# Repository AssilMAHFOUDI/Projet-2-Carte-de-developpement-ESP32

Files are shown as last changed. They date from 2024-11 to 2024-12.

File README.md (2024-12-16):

Le but de cette carte électronique est de servir de plateforme polyvalente et flexible pour
différentes applications. Elle peut être alimentée de plusieurs manières, ce qui permet une
adaptabilité en fonction des sources d’énergie disponibles.
Elle est aussi dotée de capteurs pour mesurer le courant et la température, ce qui peut être
utile pour le suivi et la surveillance de performances ou pour la protection de dispositifs.
L'interface homme-machine (IHM), avec un buzzer, une LED, et une connectivité BLE, permet
une interaction facile avec l’utilisateur.
La possibilité de boot et reset matériel permet une gestion directe de la carte. Enfin, la
compatibilité avec les modules MikroBus et Grove garantit une extension facile, ajoutant des
fonctionnalités supplémentaires pour diverses applications.
###plus d'informations dans le rapport

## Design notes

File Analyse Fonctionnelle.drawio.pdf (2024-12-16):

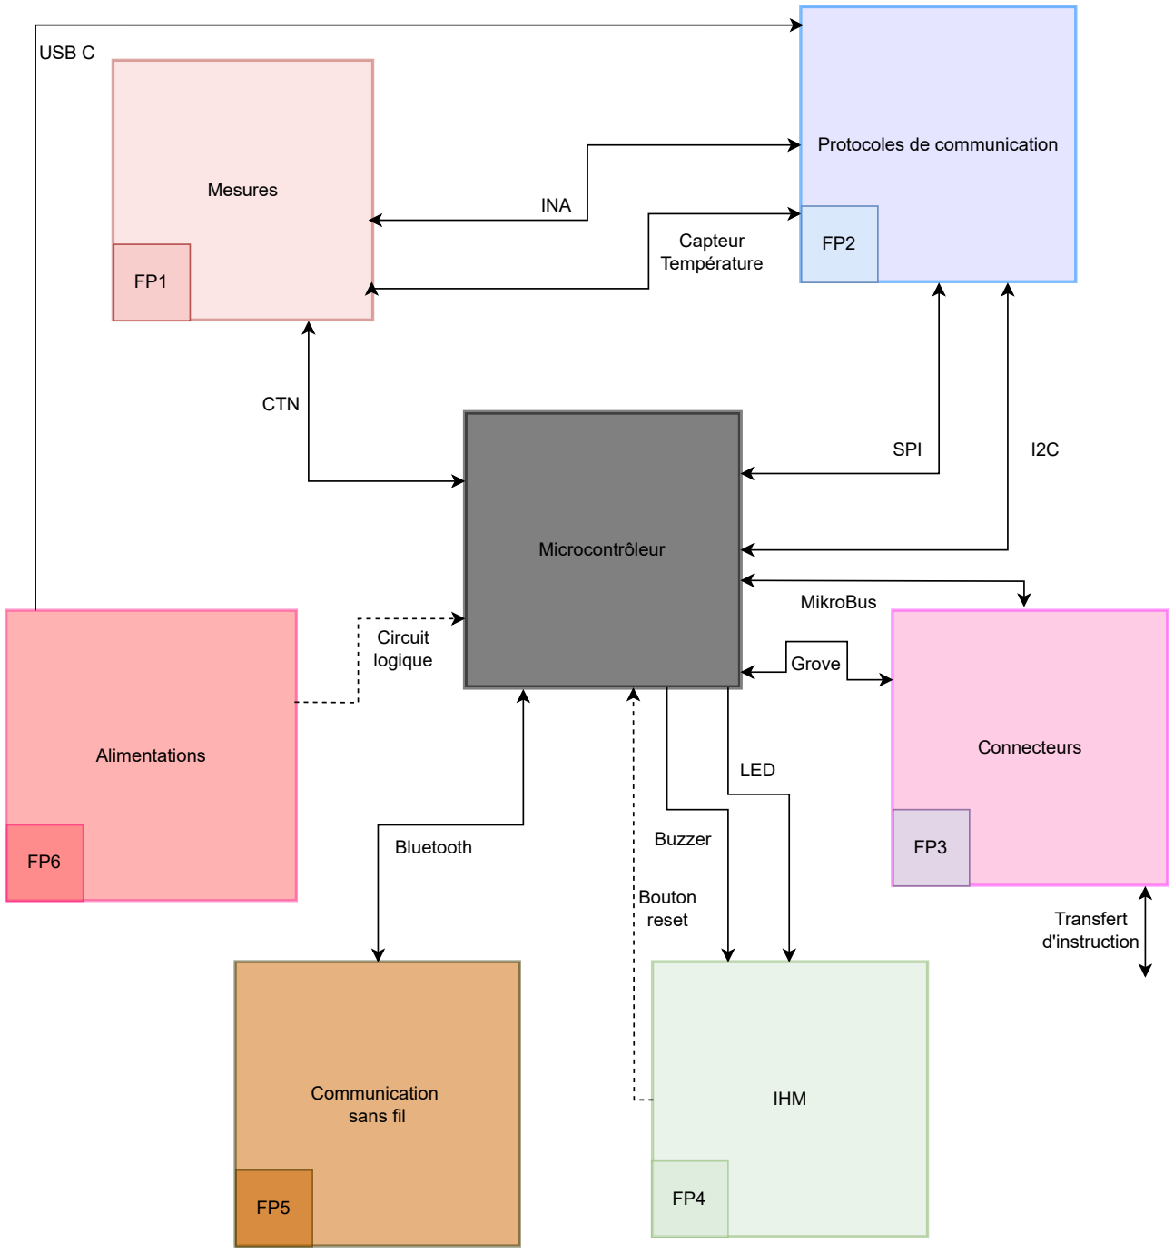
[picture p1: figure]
Alimentations; Microcontrôleur; Mesures; Connecteurs; Communication sans fil; IHM; Capteur Température; INA; USB C; Bluetooth; CTN; Protocoles de communication; SPI; Circuit logique; Buzzer; Bouton reset; LED; MikroBus; Grove; Transfert d'instruction

Légende :

Signal npn géré avec le
logiciel

Signal géré avec le logiciel

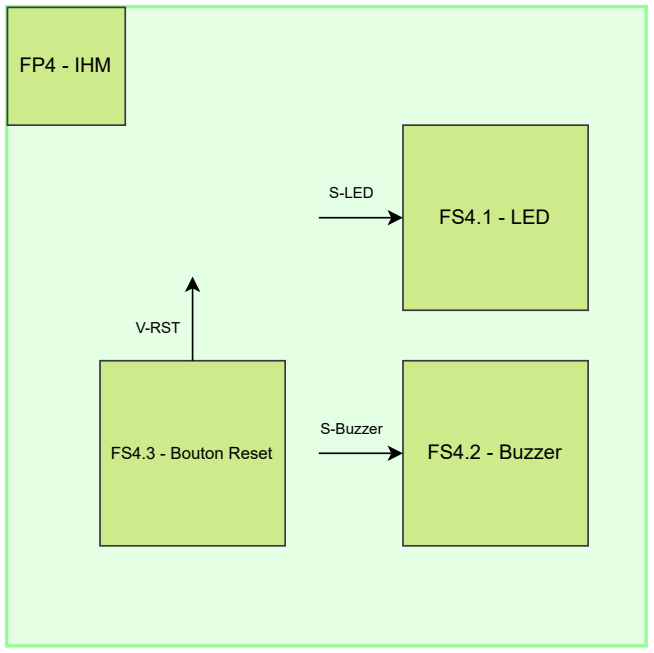
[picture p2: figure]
FP4 - IHM; FS4.1 - LED; S-LED; FS4.2 - Buzzer; S-Buzzer; FS4.3 - Bouton Reset; V-RST
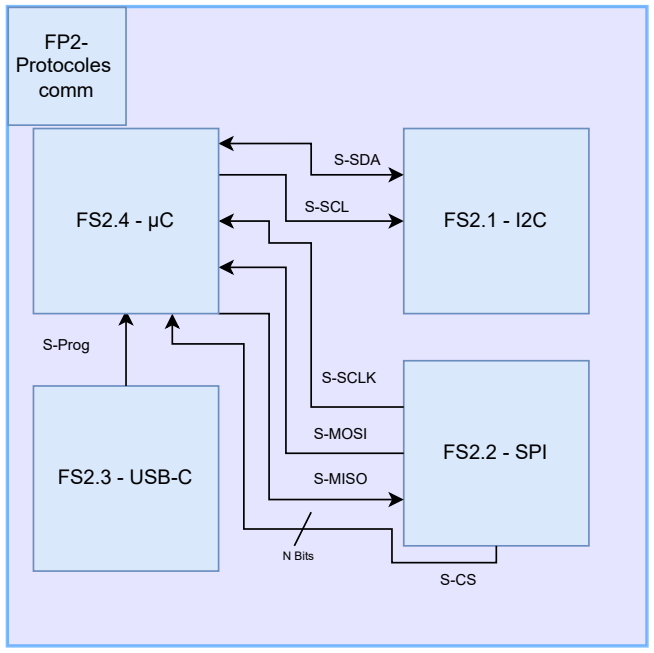
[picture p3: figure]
FP2- Protocoles comm; S-SDA; S-SCL; FS2.2 - SPI; S-SCLK; S-MOSI; S-MISO; N Bits; FS2.3 - USB-C; S-Prog
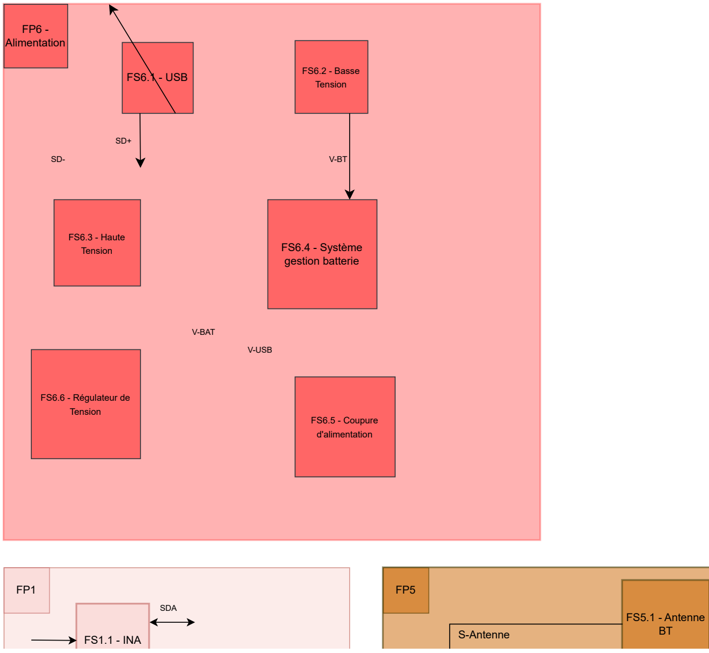
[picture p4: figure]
FP6 - Alimentation; FS6.1 - USB; FS6.4 - Système gestion batterie; V-BAT; FS6.2 - Basse Tension; V-USB; FS6.3 - Haute Tension; FS6.6 - Régulateur de Tension; FS6.5 - Coupure d'alimentation; FS1.1 - INA; SDA; FS5.1 - Antenne BT S-Antenne

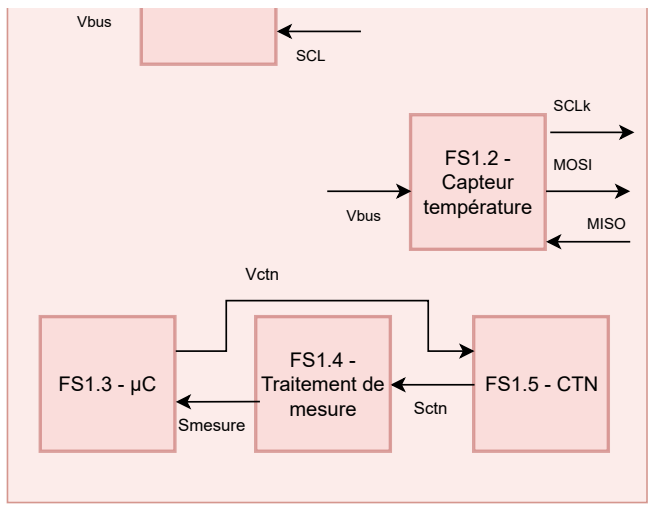
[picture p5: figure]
Vbus; SCL; FS1.2 - Capteur température; FS1.5 - CTN; SCLk; MOSI; MISO Vbus; Sctn; FS1.4 - Traitement de mesure; Smesure; Vctn

Microcontrôleur

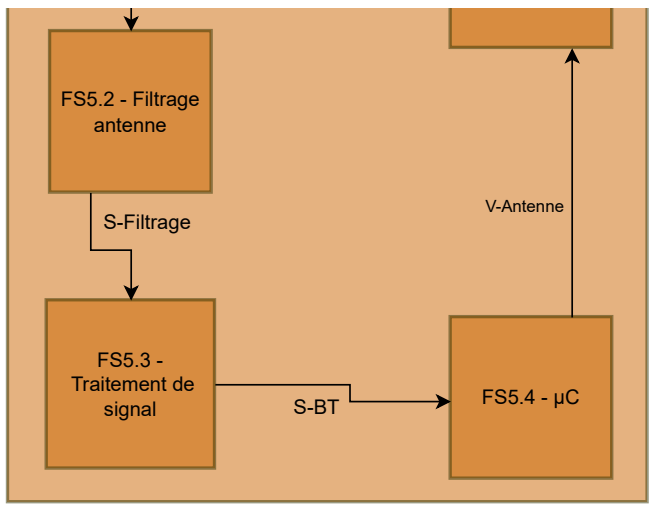
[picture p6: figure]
FS5.2 - Filtrage antenne; V-Antenne; FS5.3 - Traitement de; signal; S-Filtrage

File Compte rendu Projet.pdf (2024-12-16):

Equipe 4
TAHIRI Manelle
MAHFOUDI Assil
RANDONNET Bertil

# Compte rendu Réalisation d’une carte de développement

## Introduction :

## Contexte du projet

## Objectif

Le but de cette carte électronique est de servir de plateforme polyvalente et flexible pour différentes applications. Elle peut être alimentée de plusieurs manières, ce qui permet une adaptabilité en fonction des sources d’énergie disponibles. Elle est aussi dotée de capteurs pour mesurer le courant et la température, ce qui peut être utile pour le suivi et la surveillance de performances ou pour la protection de dispositifs. L’interface
homme-machine (IHM), avec un buzzer, une LED, et une connectivité BLE, permet une interaction facile avec l’utilisateur. La possibilité de boot et reset matériel permet une gestion directe de la carte. Enfin, la compatibilité avec les modules MikroBus et Grove garantit une extension facile, ajoutant des fonctionnalités supplémentaires pour diverses applications.

E

q

uip

e

4
TA

HIRI M

a

n

elle
M

A

H

F

O

U

DI A

s

## sil RANDONNET Bertil Jalon 1 : Analyses fonctionnelles

AF1

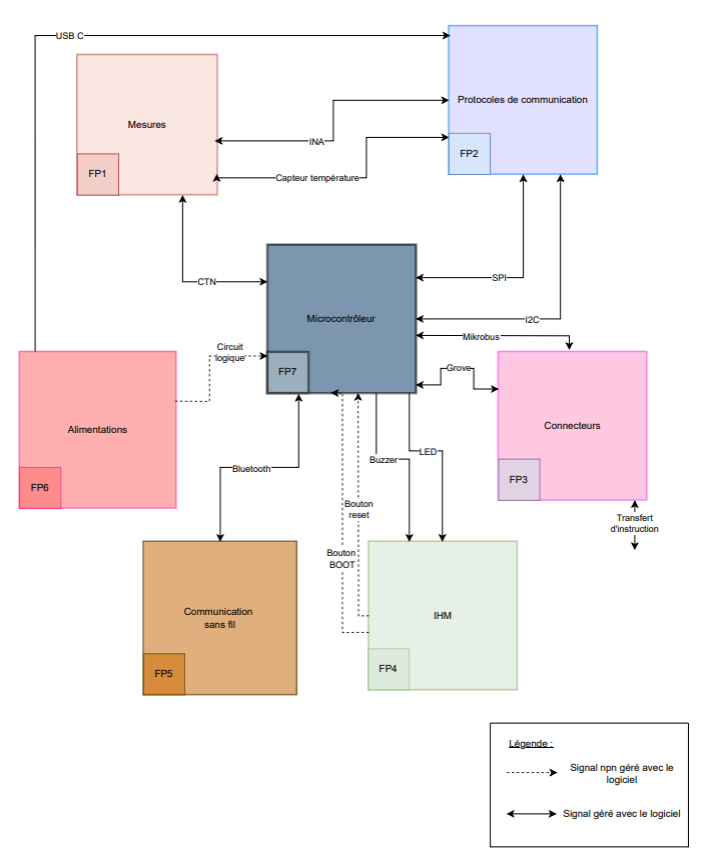
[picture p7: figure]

AF2

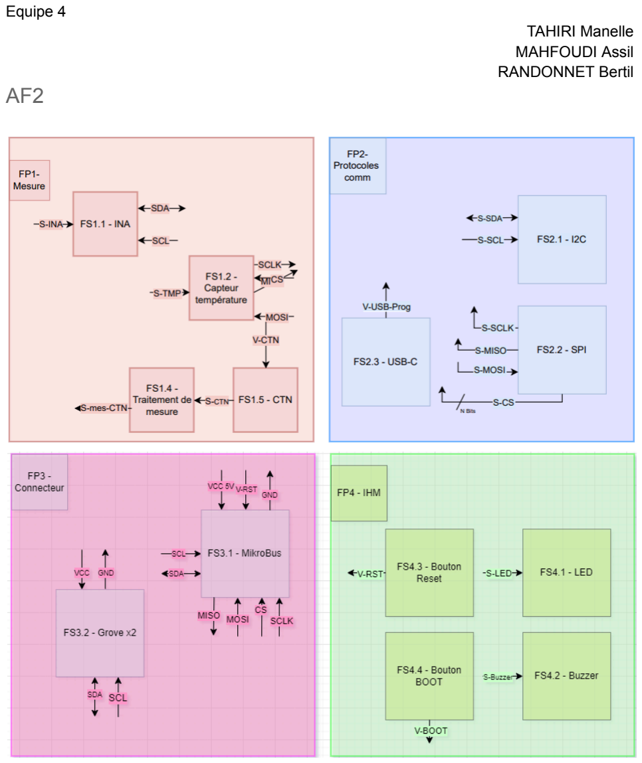
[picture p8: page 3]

E

q

uip

e

4
TA

HIRI M

a

n

elle
M

A

H

F

O

U

DI A

s

sil RANDONNET Bertil

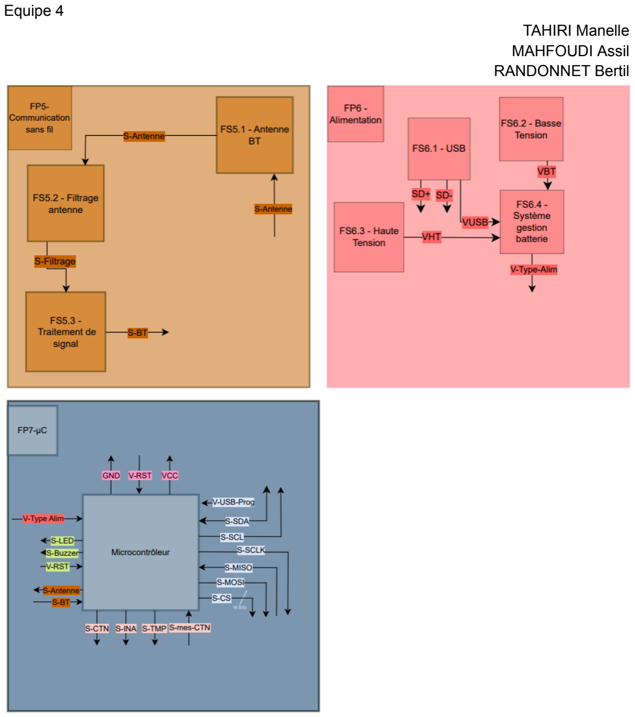
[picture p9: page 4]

E

q

uip

e

4
TA

HIRI M

a

n

elle
M

A

H

F

O

U

DI A

s

sil RANDONNET Bertil

## Jalon 2 : Réalisation schématique

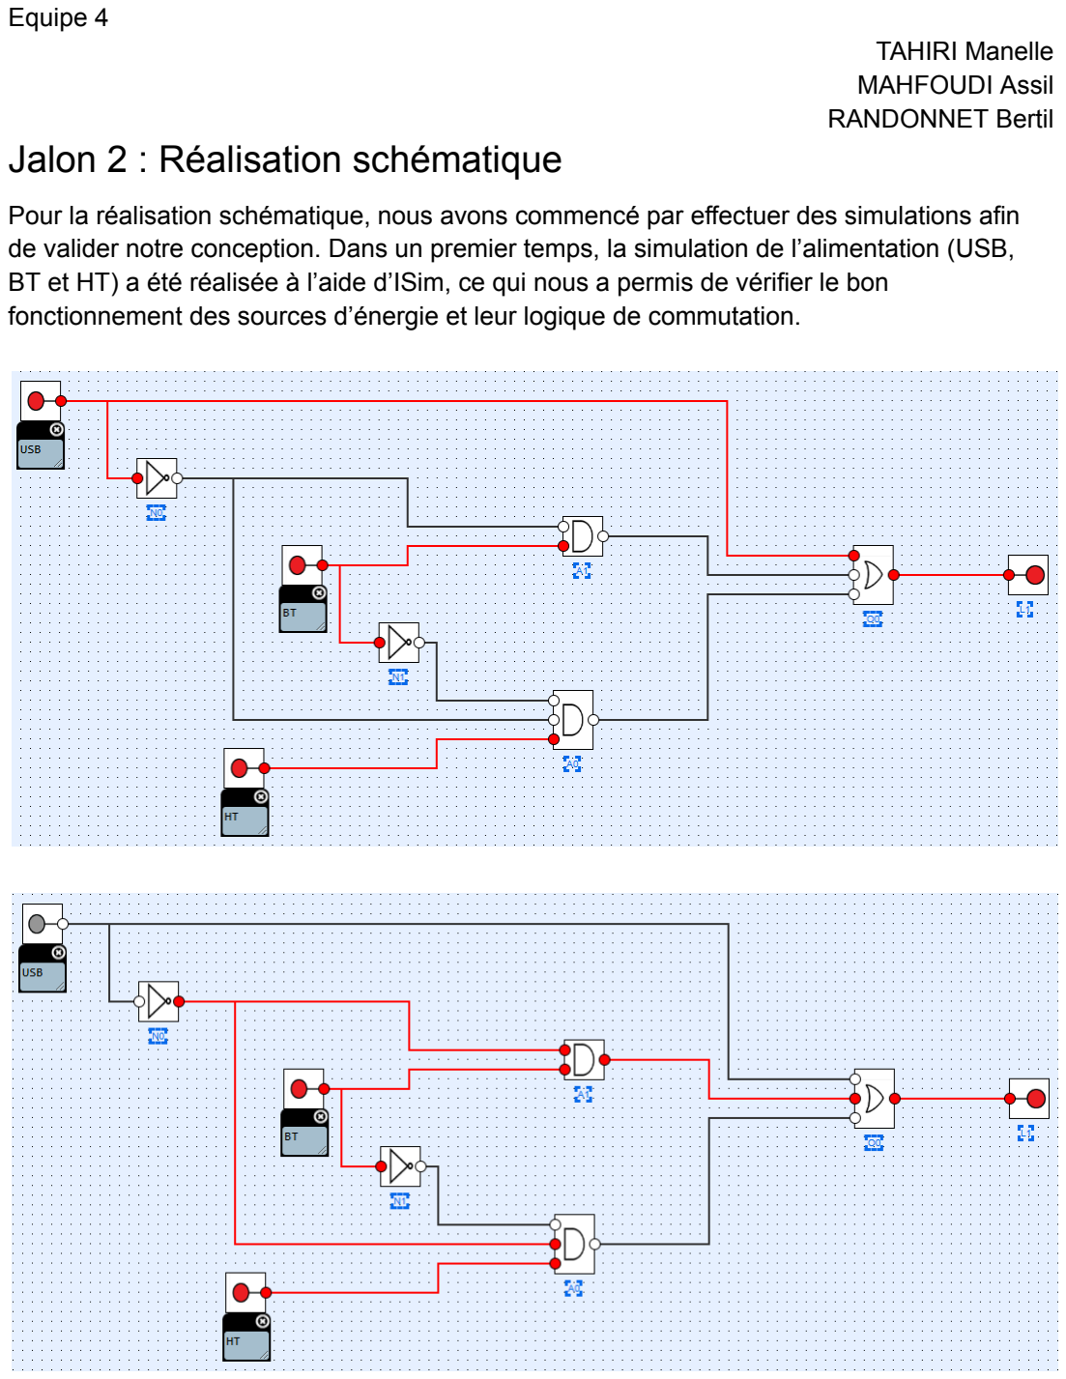
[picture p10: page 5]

MAHFOUDI Assil
RANDONNET Bertil

Pour la réalisation schématique, nous avons commencé par effectuer des simulations afin de valider notre conception. Dans un premier temps, la simulation de l’alimentation (USB, BT et HT) a été réalisée à l’aide d’ISim, ce qui nous a permis de vérifier le bon fonctionnement des sources d’énergie et leur logique de commutation.

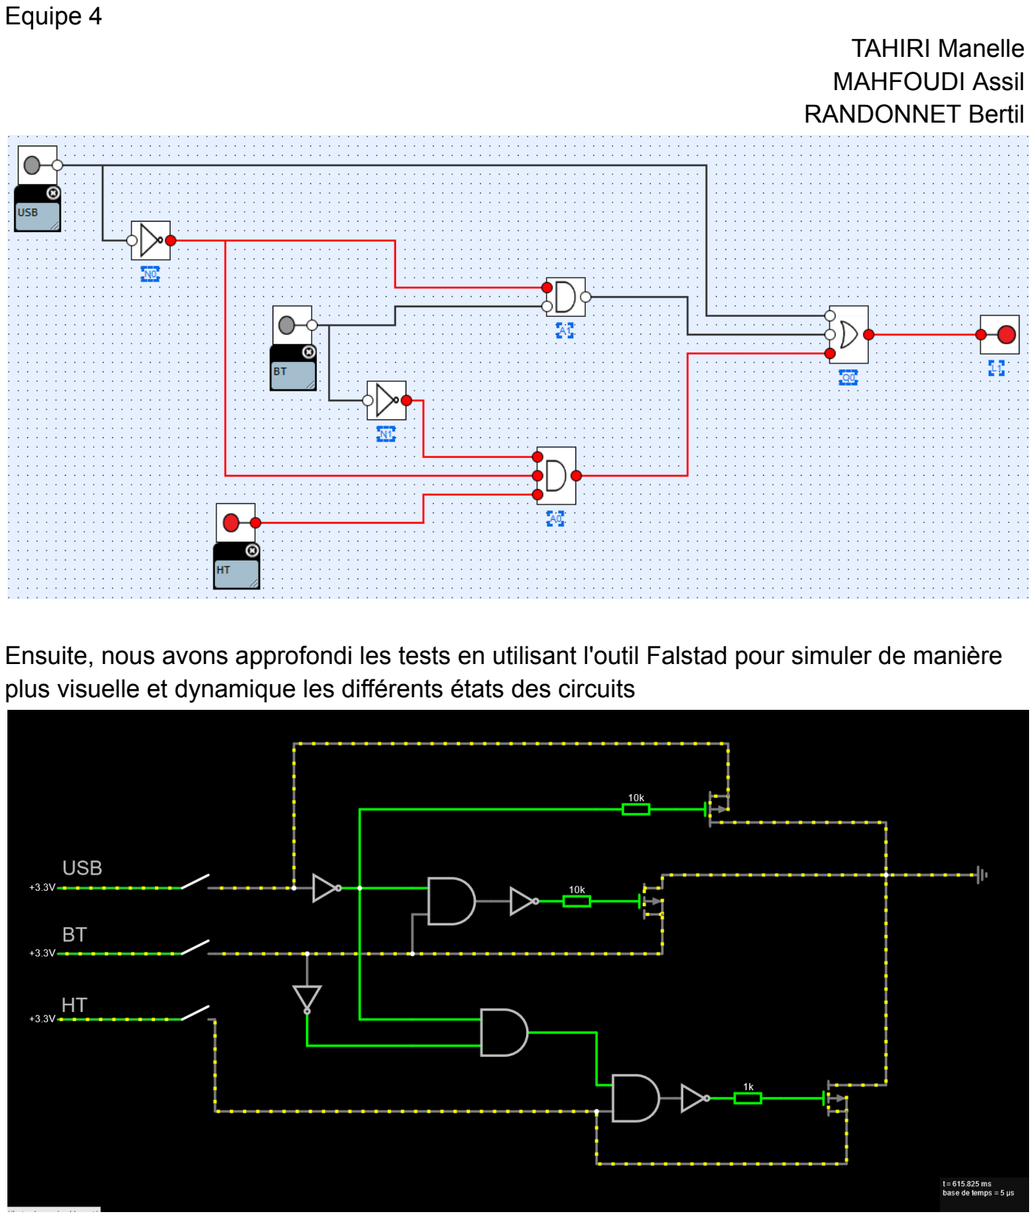
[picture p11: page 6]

MAHFOUDI Assil
RANDONNET Bertil

Ensuite, nous avons approfondi les tests en utilisant l'outil Falstad pour simuler de manière plus visuelle et dynamique les différents états des circuits

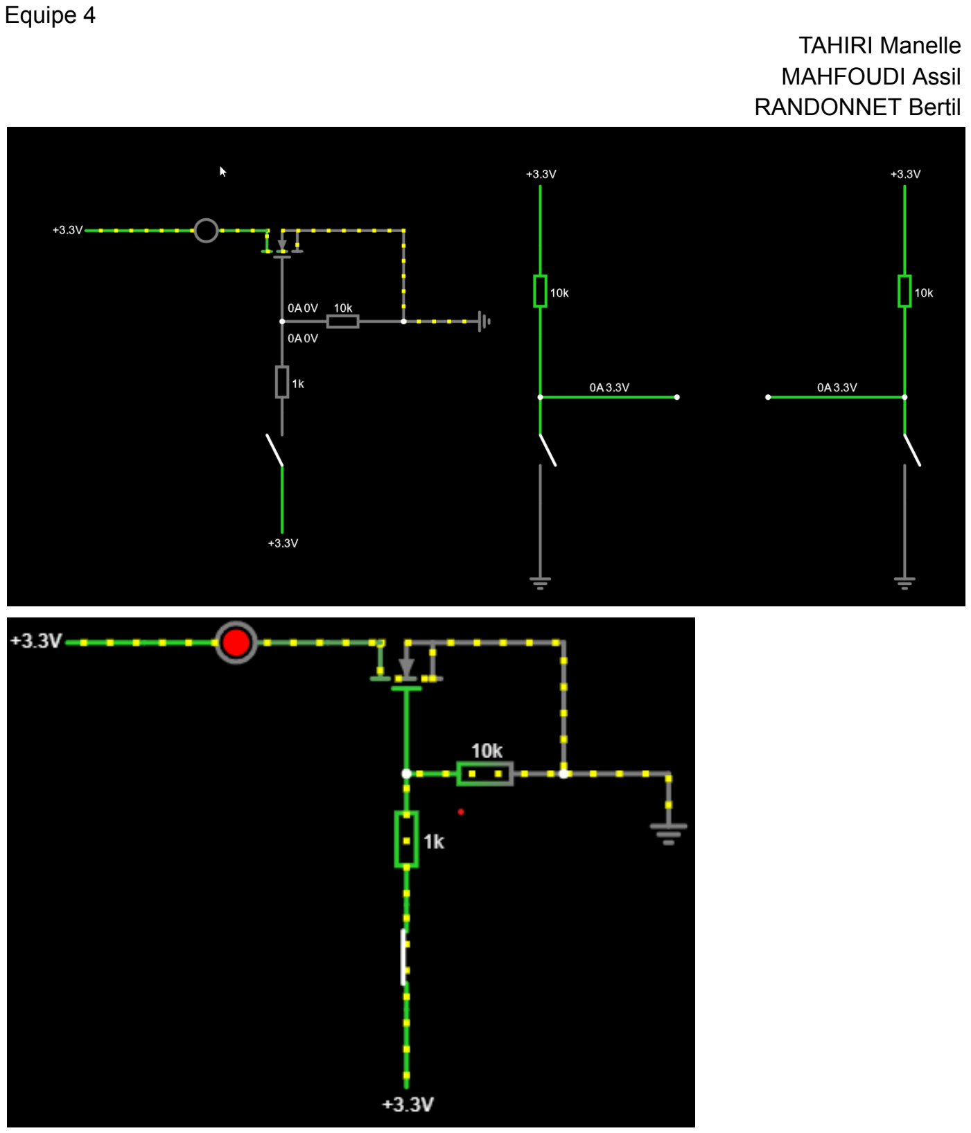
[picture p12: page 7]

E

q

uip

e

4
TA

HIRI M

a

n

elle
M

A

H

F

O

U

DI A

s

sil RANDONNET Bertil

MAHFOUDI Assil
RANDONNET Bertil

## Altium :

Schématique sensors :

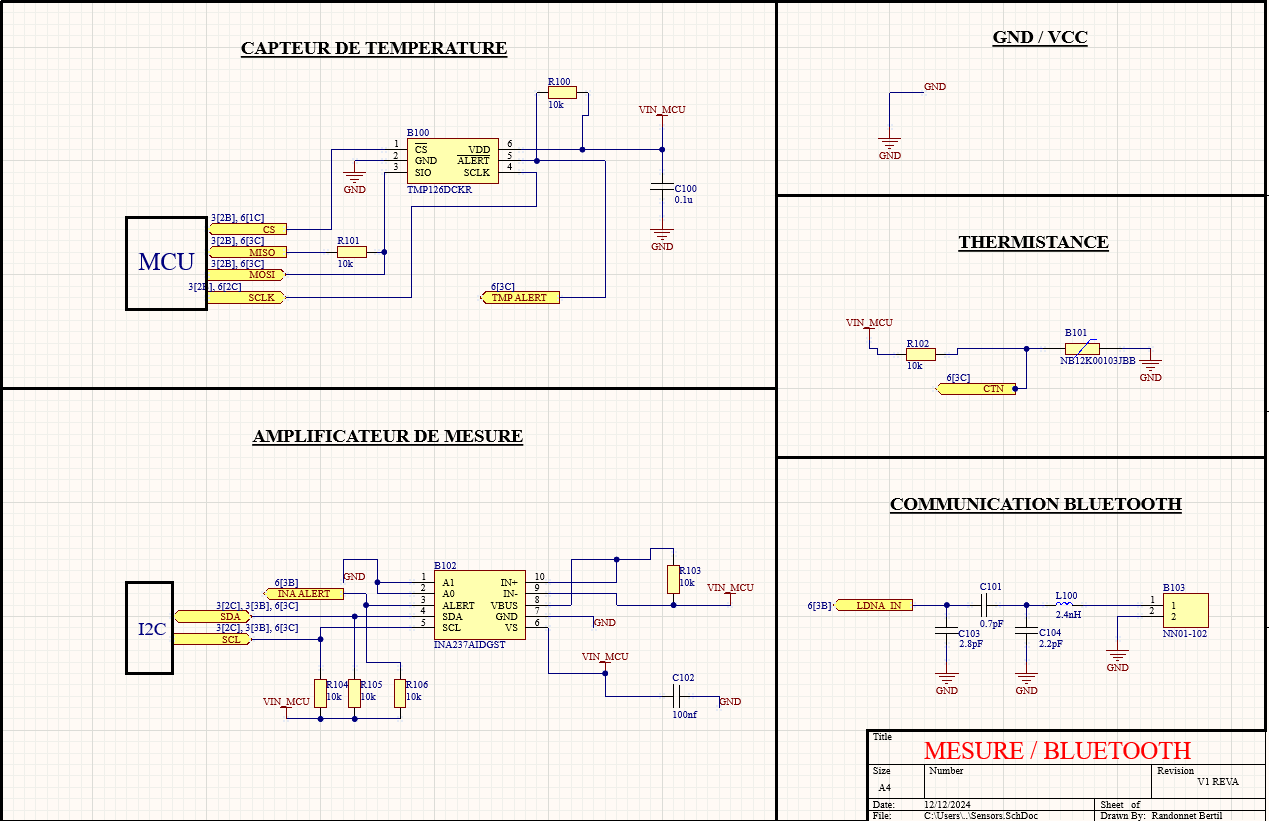
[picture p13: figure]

### 1. Capteur de température

Ce bloc utilise le capteur TMP126DKCR, qui communique via un bus SPI avec le microcontrôleur (MCU). Voici les points clés :
Broches SPI (CS, MOSI, MISO, SCLK) : Connectées au MCU pour transmettre les données de température.
Broche ALERT : Sert à signaler au MCU des conditions spécifiques, comme une surchauffe.
- Résistance de pull-up (R101, 10 kΩ) : Maintient la ligne de communication en état stable lorsqu’elle n’est pas utilisée.
- Condensateur de découplage (C100, 0.1 µF) : Filtre les bruits parasites sur l’alimentation du capteur.
- Alimentation : Le capteur est alimenté par le VIN_MCU, une source stabilisée à 3,3 V.

Ce sous-système permet de mesurer la température et d’envoyer les données au MCU pour traitement.

Annexe 1 : TMP126DCKR (https://www.ti.com/lit/ds/symlink/tmp126.pdf?ts=1733985599589)

MAHFOUDI Assil
RANDONNET Bertil

### 2. Amplificateur de mesure

Le bloc amplificateur utilise le circuit INA237AIDGST, qui est un amplificateur de précision capable de mesurer des tensions et des courants. Points essentiels :

- Entrées IN+ et IN- : Reçoivent le signal différentiel à amplifier, provenant du circuit mesuré.
- Sortie vers le bus I2C (SCL, SDA) : Les données amplifiées sont envoyées au MCU pour analyse via un bus I2C.
- Résistances de pull-up (R104, R106) : Stabilisent les lignes SDA et SCL en évitant les états flottants.
- Condensateur de découplage (C102, 100 nF) : Réduit les bruits électriques sur l’alimentation de l’amplificateur.

Ce circuit permet de mesurer avec précision des courants ou tensions faibles.

Annexe 2 : INA237AIDGST (https://www.ti.com/lit/ds/symlink/ina237.pdf?ts=1733957062465)

### 3. Thermistance

La thermistance NBI12K00103JBB est utilisée pour des mesures analogiques de température. Fonctionnement :

- Résistance pull-up (R102, 10 kΩ) : Forme un diviseur de tension avec la thermistance, permettant de convertir les variations de résistance en signal analogique mesurable.
- Connexion au VIN_MCU : Fournit une alimentation stable à la thermistance.

Ce composant fournit une mesure alternative ou redondante de la température.

Annexe 3 : NBI12K00103JBB (https://www.mouser.fr/datasheet/2/40/nb21_nb12_nb20-3165367.pdf)

### 4. Communication Bluetooth

Le bloc Bluetooth utilise un module NN01-102 pour établir une communication sans fil. Points essentiels :

- LDNA_IN : Une ligne d'entrée pour l’antenne Bluetooth.
- Circuit d'accord d'antenne (C101, L100, C103, C104) : Optimise les performances de l’antenne en adaptant l’impédance.
- Condensateurs (C101, C103, C104) : Assurent le filtrage des hautes fréquences.
- Inductance (L100, 2.4 nH) : Contribue à l'accord en série avec les condensateurs.
- Alimentation via VIN_MCU : Alimente le module Bluetooth.

MAHFOUDI Assil
RANDONNET Bertil
Ce bloc permet d'établir une communication sans fil entre l'ESP32 et un appareil externe, comme un smartphone ou un ordinateur.

Annexe 4 : NN01-102 (https://www.tme.eu/Document/b8911a508f32e0255df5b480cdb4cea1/C10GS-DKK_INS.pdf)

Schématique protocole de communication :

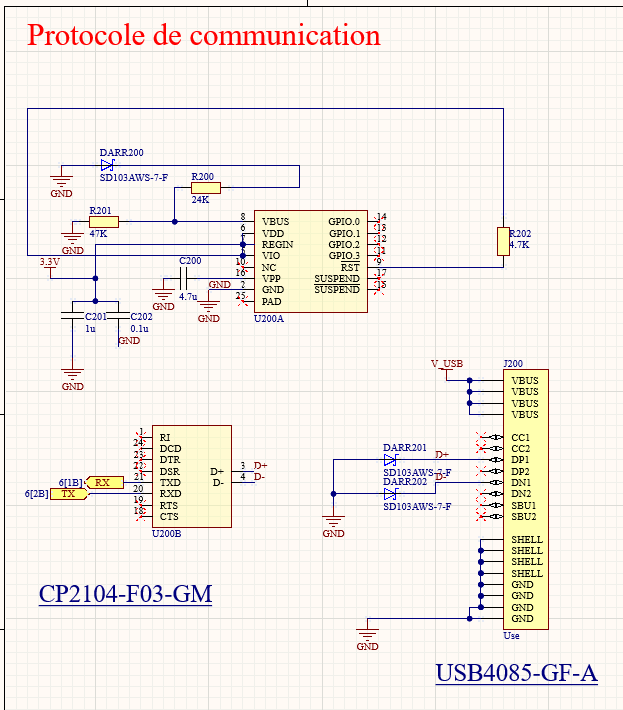
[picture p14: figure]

MAHFOUDI Assil
RANDONNET Bertil

### 1. USB4085-GF-A (Connecteur USB)

Ce composant représente le connecteur USB principal (J200). Points importants :

- Broches VBUS et GND : Assurent l'alimentation (+5 V) pour les circuits connectés à l'USB.
- Broches D+ et D- : Lignes de données différentielles utilisées pour la communication USB.
- SHIELD : Connexion à la masse pour l'écran du câble USB, réduisant les interférences électromagnétiques.

Ce bloc fournit l'interface physique pour connecter la carte à un port USB externe, permettant l'alimentation et l'échange de données.

Annexe 5 : USB4085-GF-A (https://eu.mouser.com/datasheet/2/837/GCT_usb4085-3240028.pdf)

### 2. CP2104-F03-GM (Convertisseur USB-UART)

Le CP2104 (U200B) est un convertisseur USB vers UART qui permet de connecter un périphérique USB à une interface série. Fonctionnement :

- Entrées D+ et D- : Reçoivent les données du connecteur USB (J200) via le bus différentiel.
- Sorties TX et RX : Fournissent une interface série (UART) pour communiquer avec le MCU.
- Broches supplémentaires (RI, DCD, DTR, etc.) : Peuvent être utilisées pour des fonctions avancées de contrôle de flux série.
- Alimentation : Alimentée en 3,3 V depuis le régulateur intégré.
- GND : Référence de masse commune.

Le CP2104 est un élément clé pour établir une liaison série entre la carte et un ordinateur ou tout autre périphérique compatible USB.

Annexe 6 : CP2104-F03-GM (https://eu.mouser.com/datasheet/2/368/cp2104-1397921.pdf)

### 3. Régulateur de tension et circuit passif

Ce sous-circuit alimente et stabilise les tensions nécessaires pour le fonctionnement du protocole USB :

- SD103AWS-7-F (DARR200, diode) : Protège contre les surtensions sur les lignes d'alimentation et évite les retours de courant.
- Résistances (R200, R201, R202) :
- R200 (24 kΩ) : participe à la configuration de la tension du régulateur.
- R201 et R202 (47 kΩ, 4,7 kΩ) : jouent un rôle dans le découplage et la stabilisation des signaux.
- Condensateurs (C200, C201, C202) :

MAHFOUDI Assil
RANDONNET Bertil
- C200 (4,7 µF) : Assure le filtrage de l’alimentation pour éviter les fluctuations de tension.
- C201 et C202 (0,1 µF, 1 µF) : Réduisent les bruits haute fréquence.

Ce bloc garantit que le convertisseur USB-UART et les composants associés reçoivent une alimentation propre et stable.

Annexe 7 : SD103AWS-7-F (https://www.mouser.fr/datasheet/2/115/DIOD_S_A0006455662_1-2542841.pdf)

### 4. Communication UART

Les lignes TX et RX établissent la communication série :

- TX (Transmitter) : Transmet les données du convertisseur USB-UART vers le microcontrôleur.
- RX (Receiver) : Reçoit les données en provenance du microcontrôleur.

Schématique connecteurs :

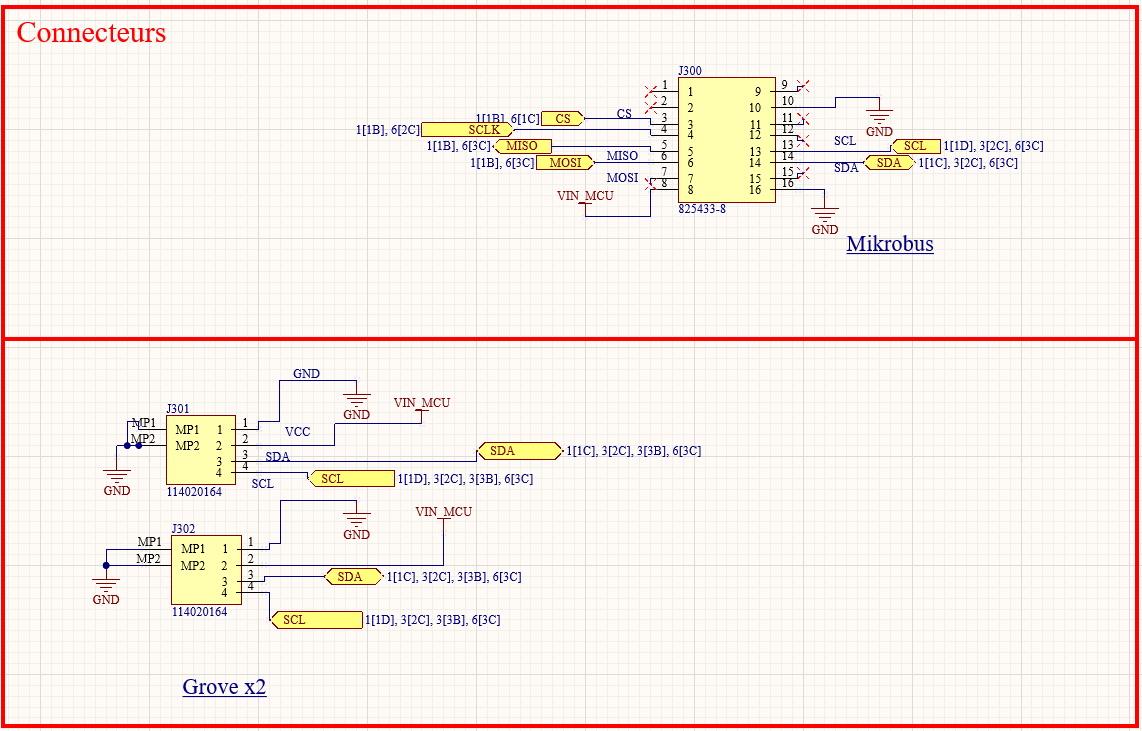
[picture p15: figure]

MAHFOUDI Assil
RANDONNET Bertil

### 1. Connecteur Mikrobus (J300)

Le connecteur Mikrobus est conçu pour accueillir des modules MikroElektronika. Il fournit une interface standard pour une communication rapide et facile entre la carte et des périphériques externes.

- Broches SPI (CS, MISO, MOSI, SCLK) :
- CS (Chip Select) : Permet de sélectionner un périphérique spécifique sur le bus SPI.
- MISO (Master In Slave Out) : Ligne utilisée pour transférer des données du périphérique esclave au maître.
- MOSI (Master Out Slave In) : Ligne utilisée pour transférer des données du maître au périphérique esclave.
- SCLK (Serial Clock) : Génère l'horloge nécessaire pour la communication SPI.
- Broches I²C (SCL, SDA) :
- SCL (Serial Clock Line) : Fournit l'horloge pour le protocole I²C.
- SDA (Serial Data Line) : Utilisée pour transférer des données bidirectionnelles entre le maître et l'esclave.
- Broches d’alimentation (VIN_MCU, GND) :
- VIN_MCU : Fournit une alimentation au module connecté.
- GND : Sert de référence pour la masse.

Ce connecteur est polyvalent et peut accueillir plusieurs modules, comme des capteurs ou des périphériques de communication, grâce à ses lignes SPI et I²C.

Annexe 8 : Mikrobus (https://www.mouser.fr/datasheet/2/418/7/ENG_CD_825433_S_baseFilename-2068619.pdf)

### 2. Connecteurs Grove (J301 et J302)

Les connecteurs Grove (J301 et J302) sont utilisés pour des modules compatibles avec le système Grove. Ces connecteurs permettent une connexion facile avec des capteurs ou des périphériques. Chaque connecteur suit une configuration standard avec 4 broches :

- VCC : Fournit l’alimentation pour les modules connectés (tirée de VIN_MCU).
- GND : Assure la masse pour les modules connectés.
- SDA (Serial Data Line) : Transmet les données pour le protocole I²C.
- SCL (Serial Clock Line) : Fournit l’horloge pour la communication I²C.

Les deux connecteurs sont parallèles, permettant la connexion de plusieurs modules Grove en même temps. Cela favorise l’évolutivité du système et la facilité d’utilisation.

Annexe 9 : Groove (https://www.mouser.fr/datasheet/2/744/Grove_Female_Header___SMD_4P_2_0mm_90D_Datasheet-3011316.pdf)

MAHFOUDI Assil
RANDONNET Bertil
Schématique IHM :

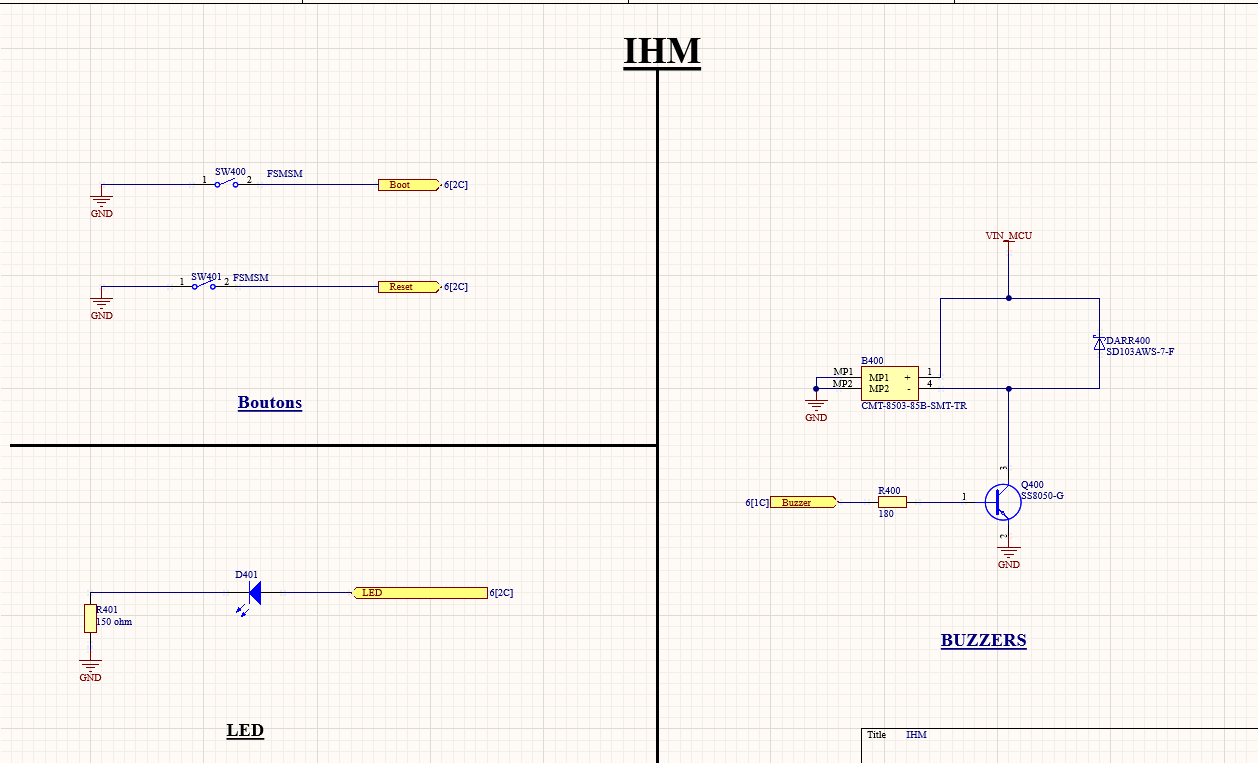
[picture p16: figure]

### 1. Boutons

Cette section contient deux boutons poussoirs SW400 et SW401.

Composants principaux :

- SW400 (Boot) : Bouton connecté à la masse (GND).
- SW401 (Reset) : Deuxième bouton également relié à la masse.
- Les deux boutons sont connectés à des signaux étiquetés Boot et Reset.

Fonctionnement :

- SW400 permet de déclencher la fonction Boot.
- SW401 permet de déclencher la fonction Reset. Ces boutons sont généralement utilisés pour forcer un redémarrage ou initialiser une carte MCU.

### 2. LED

Cette section comprend une LED pour signaler l'état du système.

Composants principaux :

- D401 : Diode LED.
- R401 (150 ohm) : Résistance de limitation de courant pour protéger la LED.
- GND : La LED est reliée à la masse pour assurer un fonctionnement sécurisé.

Fonctionnement :

MAHFOUDI Assil
RANDONNET Bertil
- Lorsque le signal LED (étiqueté 6[2C]) est activé, la LED s'allume en passant un courant contrôlé à travers R401.
- Cela permet d'indiquer visuellement un état spécifique du système.

### 3. Buzzers

Cette partie contrôle un buzzer pour produire un signal sonore.

Composants principaux :

- B400 : Relais CMT8503-SSB-SMT-TR pour activer le buzzer.
- Q400 (SS8550-G) : Transistor PNP utilisé comme interrupteur pour contrôler l'alimentation du buzzer.
- R400 (180 ohm) : Résistance pour limiter le courant traversant la base du transistor.
- DARR400 (SD103AWS-7-F) : Diode pour la protection contre les surtensions (anti-retour de courant).
- Buzzer : Signal étiqueté 6[1C] qui active le buzzer.

Fonctionnement :

1. Le relais B400 permet de basculer l'alimentation vers le buzzer.
2. Le transistor Q400 agit comme un interrupteur pour contrôler l'activation du buzzer.
3. La résistance R400 limite le courant entrant dans la base du transistor pour protéger le circuit.
4. La diode DARR400 protège contre les pics de tension indésirables.

Lorsque le signal Buzzer (6[1C]) est activé :

- Le transistor se met en conduction.
- Le buzzer est alimenté, générant un signal sonore.

MAHFOUDI Assil
RANDONNET Bertil
Schématique alimentation :

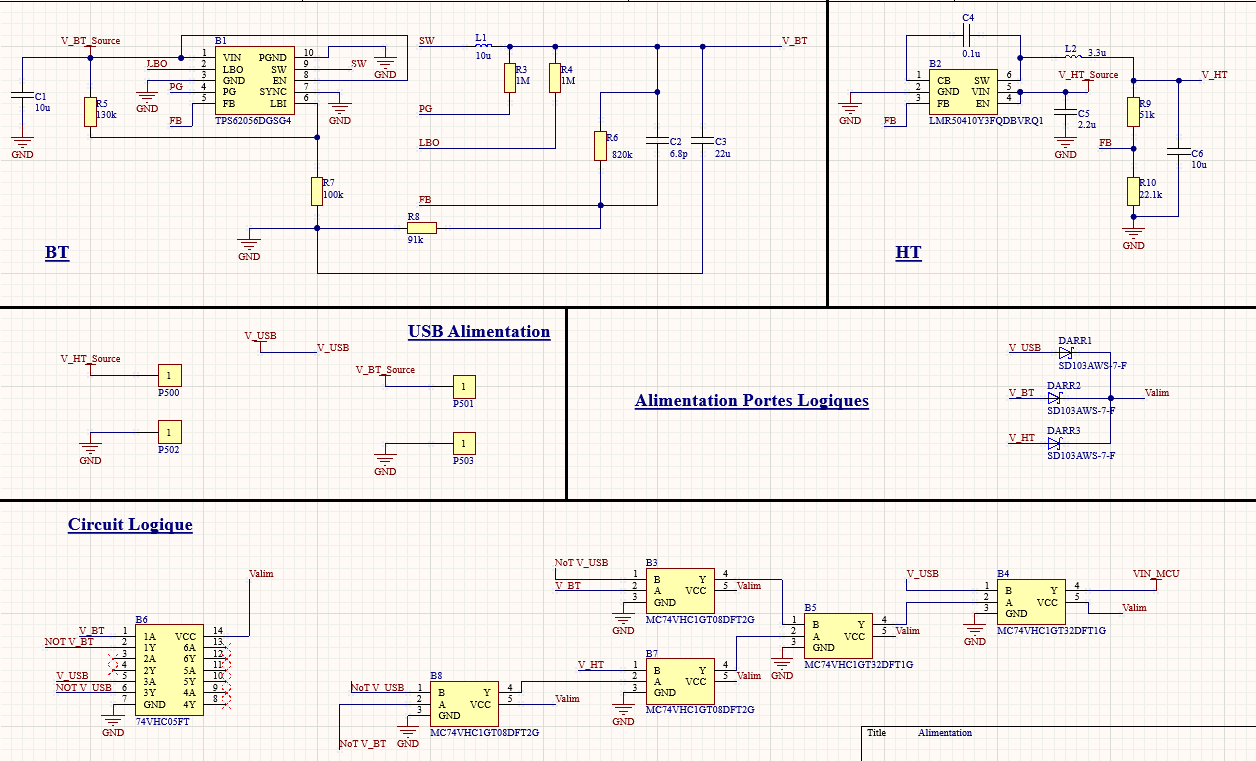
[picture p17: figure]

### 1. Alimentation BT (Bloc BT)

Ce bloc utilise le TPS62050DGSG4, un régulateur abaisseur (DC-DC) pour générer une tension V_BT.
Composants principaux :
- Entrée (V_BT_Source) : Alimentation d'entrée pour le régulateur.
- C1 (10uF) : Condensateur pour stabiliser la tension d'entrée.
- R5 (100k) et R7 (100k) : Résistances pour configurer la tension de sortie via la broche FB (Feedback).
- L1 (2.2uH) : Inductance pour le filtrage de la sortie.
- C2 (6.8pF), C3 (22uF) : Condensateurs pour réduire les ondulations à la sortie.
- R8 (91k), R6 (820k) : Résistances pour le contrôle du feedback.

Fonctionnement : Le régulateur abaisse la tension d'entrée pour fournir une tension stable V_BT. Les résistances de feedback (FB) permettent de définir cette tension de sortie.

Annexe 10 : TPS62050DGSG4 (https://www.ti.com/lit/ds/symlink/tps62050.pdf?ts=1734194855394)

MAHFOUDI Assil
RANDONNET Bertil

### 2. Alimentation HT (Bloc HT)

Ce bloc utilise le LMR50410Y3FDBVRQ1, un autre régulateur abaisseur pour générer une tension V_HT.

Composants principaux :

- Entrée (V_HT_Source) : Source d'alimentation d'entrée.
- C4 (0.1uF) et C5 (2.2uF) : Condensateurs pour le filtrage côté entrée et sortie.
- L2 (3.3uH) : Inductance pour stabiliser la tension de sortie.
- C6 (10uF) : Condensateur de sortie pour réduire les ondulations.
- R9 (51k), R10 (22.1k) : Résistances pour le feedback.

Fonctionnement : Le régulateur ajuste la tension d'entrée pour produire une tension de sortie V_HT, définie par les résistances de feedback.

Annexe 11 : LMR50410Y3FDBVRQ1 (https://www.ti.com/lit/ds/symlink/lmr50410-q1.pdf?ts=1734160816247)

### 3. USB Alimentation

Cette section inclut trois connecteurs P500, P501, et P502 pour distribuer les différentes tensions d'alimentation (V_USB, V_BT_Source, V_HT_Source) ainsi que la masse GND.

Rôle : Ces connecteurs permettent de fournir des sources d'alimentation externes pour tester et alimenter d'autres composants du circuit.

MAHFOUDI Assil
RANDONNET Bertil
Schématique MCU :

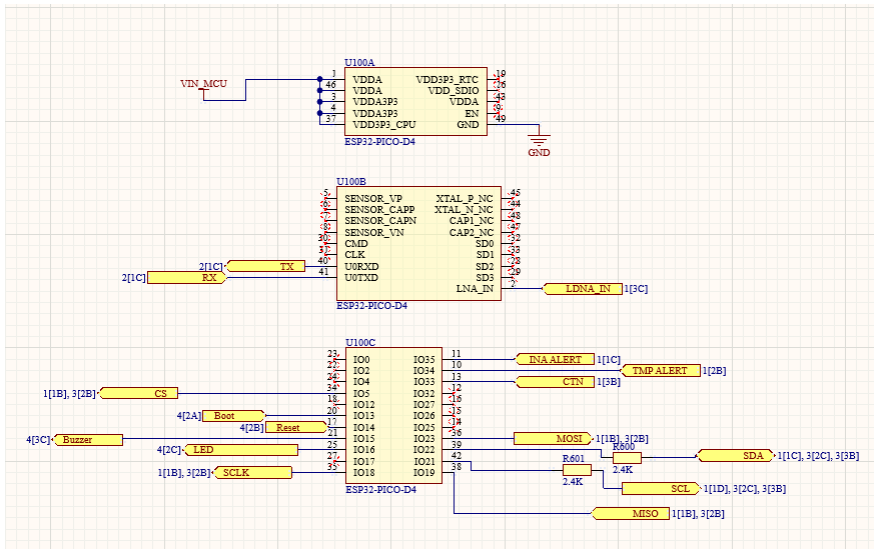
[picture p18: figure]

### 1. Alimentation du MCU

- Broches d'alimentation :
- VIN_MCU : Alimentation principale fournie au microcontrôleur, connectée aux broches VDDA3P3, VDDA.
- Les broches VDDA, VDD33_CPU alimentent respectivement les parties analogiques et numériques de l'ESP32.
- La masse (GND) est commune à tout le circuit et connectée aux broches de référence GND.
- Stabilité :
- Le fait d'alimenter correctement ces broches assure un fonctionnement stable et performant du module ESP32.

### 2. Broches de Communication Série (UART)

- UART0 :
- TX (Transmission) : Broche 2[1C] utilisée pour envoyer des données série.
- RX (Réception) : Broche 2[1C] utilisée pour recevoir des données série.
- Utilisation : Ces broches servent à la programmation et au débogage de l'ESP32 via UART.
3. Interface SPI (Serial Peripheral Interface)
- CS (Chip Select) : Broche permettant de sélectionner un périphérique SPI.

MAHFOUDI Assil
RANDONNET Bertil
- SCLK (Serial Clock) : Broche 1[1B], 3[2B] qui génère l'horloge pour la communication SPI.
- MOSI (Master Out Slave In) : Broche MOSI permet l'envoi de données du maître vers l'esclave.
- MISO (Master In Slave Out) : Broche MISO pour recevoir les données de l'esclave.
- Utilisation : SPI est utilisé pour connecter des composants externes comme des capteurs, écrans, ou mémoires externes.
4. Interface I2C (Inter-Integrated Circuit)
- SCL (Serial Clock Line) : Broche d'horloge 1[1D], 3[2C], 3[3B].
- SDA (Serial Data Line) : Broche de données 1[1C], 3[2C], 3[3B].
- Pull-up Résistances : On observe des résistances R601 et R602 de 2.4kΩ sur SDA et SCL pour garantir des niveaux logiques corrects.
- Utilisation : L'I2C permet de connecter des périphériques comme des capteurs INA ALERT ou TMP ALERT.

### 5. Boutons et Entrées/Sorties (GPIO)

- Boot et Reset :
- Boot : Connecté à 4[2A], permet de mettre le MCU en mode programmation (Flash).
- Reset : Connecté à 4[2C], réinitialise l'ESP32.
- Buzzer :
- Connecté sur GPIO dédié, activé par un signal logique.
- LED :
- Connectée via une résistance à la broche GPIO, utilisée pour des signaux visuels simples.

### 6. Autres Broches

- INA ALERT et TMP ALERT :
- Connectés à des GPIO pour remonter des alertes provenant de capteurs externes.
- LDNA_IN :
- Entrée numérique pour récupérer un signal externe.

MAHFOUDI Assil
RANDONNET Bertil
Problèmes Rencontrés :
1) Alimentation du circuit analogique : comme le circuit analogique est celui qui doit déterminer l’alimentation du microcontrôleur on devait trouver une solution pour alimenter les blocs logiques, sans avoir l’idée de quelle alimentation est active ou pas.
2) Antenne Bluetooth :
Ayant des connaissances limitées en radiofréquence, l’antenne Bluetooth représente un véritable défi pour notre équipe. Nous avons étudié la fiche technique du composant et mené des recherches approfondies sur le web afin de mieux comprendre les principes de conception et d’acquisition liés à cette antenne.
3) PCB : Lors du routage, nous avons pu rencontrer différentes erreurs soit un total approximatif de 2000 erreurs notamment des erreurs “Clearance”, “Solder Mask”

Solution :

1) Avoir toutes les sources comme possibilité d'activer les blocs logiques. De ce fait on devrait avoir les alimentations au même niveau d’alimentation (3V3) il fallait aussi prendre en compte le courant et d'éventuels retour du courant. C’est pour cela que les diodes ont été rajoutées. Et à la fin nous avons eu ce schéma :

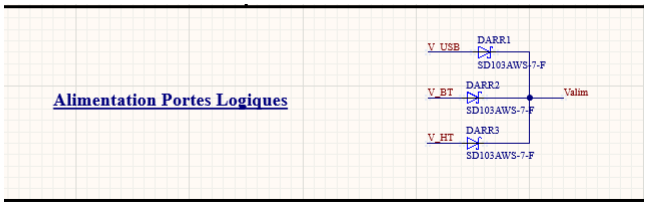
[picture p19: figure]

2) Pour exploiter efficacement les signaux d’une antenne Bluetooth, l’utilisation d’un filtre est indispensable. Nous avons opté pour un filtre passe-bande, car notre objectif se concentre sur une plage de fréquences bien spécifique.

Après de nombreuses recherches et analyses, nous avons identifié le circuit qui répondait à nos besoins, comme décrit dans l’annexe 04.

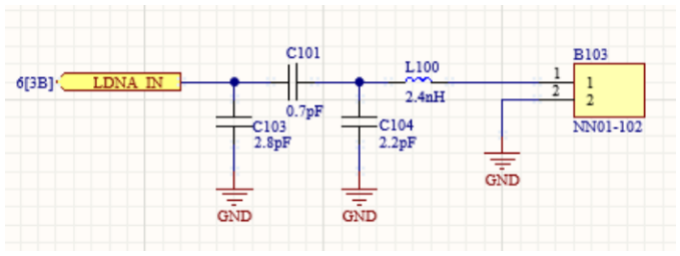
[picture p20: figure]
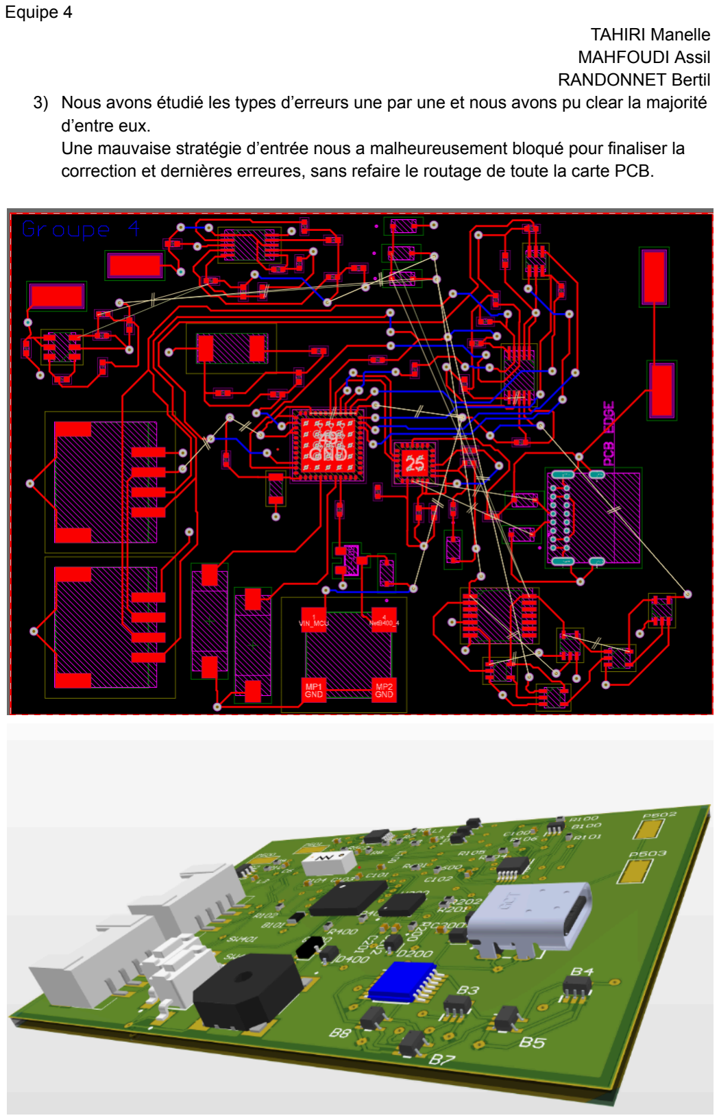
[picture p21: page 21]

MAHFOUDI Assil
RANDONNET Bertil
3) Nous avons étudié les types d’erreurs une par une et nous avons pu clear la majorité d’entre eux.
Une mauvaise stratégie d’entrée nous a malheureusement bloqué pour finaliser la correction et dernières erreures, sans refaire le routage de toute la carte PCB.

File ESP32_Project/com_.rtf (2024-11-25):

https://www.mouser.fr/datasheet/2/268/MCHP_S_A0010728890_1-2521060.pdf

MCP73831T-3ACI/OT
579-MCP73831T-3ACIOT

https://www.mouser.fr/ProductDetail/Microchip-Technology/MCP73831T-3ACI-OT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

—————————————————————————————————

https://www.digikey.fr/en/products/detail/CP2104-F03-GM/336-2008-5-ND/2486177?curr=usd
CP2104-F03-GM

—————————————————————————————————

https://www.mouser.fr/ProductDetail/AP-Memory/APS1604M-3SQR-SN?qs=IS%252B4QmGtzzpULD7HVv5Qww%3D%3D

PSRAM

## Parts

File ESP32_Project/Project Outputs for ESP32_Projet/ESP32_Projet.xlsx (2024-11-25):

PN | Description | Comment | Designator | Fabricant | PN_Fab | Package | Footprint | Qualif | Temp | Tol | Volt | Puissance | Quantity | Lien
not use | Antennes Compact Reach Xtend 2.4 GHz | NN01-102 | B200 | Ignion | NN01-102 |  |  |  |  |  |  |  | 1 | https://www.mouser.fr/ProductDetail/Ignion/NN01-102?qs=bAKSY%2FctAC74AFavC%252BjOHQ%3D%3D
not use | Capacitor | 1uF | C100, C102, C104, C107, C201, C203, C204 | Murata Electronics | GRM155R61E105MA12D | 0402 |  |  |  | 20% |  |  | 7 | https://www.mouser.fr/ProductDetail/Murata-Electronics/GRM155R61E105MA12D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
not use | Capacitor | 0.1uF | C101, C103, C110 | Murata Electronics | GRM155R61C104KA88J | 0402 |  |  |  | 10% |  |  | 3 | https://www.mouser.fr/ProductDetail/Murata-Electronics/GRM155R61C104KA88J?qs=EsazKz6kkP2%252B3xHQUDEZoQ%3D%3D
not use | Capacitor | 1nF | C105 | Murata Electronics | GRT1555C1H102FA02D | 0402 |  |  |  | 1% |  |  | 1 | https://www.mouser.fr/ProductDetail/Murata-Electronics/GRT1555C1H102FA02D?qs=hd1VzrDQEGi3r1G6fgepQQ%3D%3D
not use | Capacitor | 4.7uF | C106, C200, C202 | Murata Electronics | GRT155D70J475ME13J | 0402 |  |  |  | 20% |  |  | 3 | https://www.mouser.fr/ProductDetail/Murata-Electronics/GRT155D70J475ME13J?qs=ufv2HEpFn%252BTkPthWI9s3Gg%3D%3D
not use | Capacitor | 1.2pF | C108 | Murata Electronics | GRM1555C1E1R2CA01D | 0402 |  |  |  | 0.25 pF |  |  | 1 | https://www.mouser.fr/ProductDetail/Murata-Electronics/GRM1555C1E1R2CA01D?qs=ouTquLLW2S4mMqEzAZk5RA%3D%3D
not use | Capacitor | 1.5pF | C109 | Murata Electronics | GRM1555C1H1R5BA01D | 0402 |  |  |  | 0.1 pF |  |  | 1 | https://www.mouser.fr/ProductDetail/Murata-Electronics/GRM1555C1H1R5BA01D?qs=ouTquLLW2S54hC6WW3CPAw%3D%3D
not use | Red, Green, Blue (RGB) 624nm Red, 525nm Green, 470nm Blue LED Indication - Discrete 2V Red, 3.3V Green, 3.3V Blue 4-SMD, No Lead | 150121M153000 | D200 | Wurth Elektronik | 150121M153000 | 0805 (2012 metric) |  |  |  |  |  |  | 1 | https://www.mouser.fr/ProductDetail/Wurth-Elektronik/150121M153000?qs=5aG0NVq1C4yYowchNNQhtg%3D%3D
not use | TVS Diode Array WE-TVS, High Speed Series - Low capazity - No leakage current - Low clamping voltage - high ESD voltage protection -- USB 1.0 - 2.0 | 824011 | D201 | Wurth Elektronik | 824011 | SOT-23-5 |  |  |  |  |  |  | 1 | https://www.mouser.fr/ProductDetail/Wurth-Elektronik/824011?qs=Wn16VcyqZWrHR48Vn%2FB8%252Bg%3D%3D
not use | Diode Array 3 Independent Schottky 40V 175mA Surface Mount 6-TSSOP, SC-88, SOT-363 | SD103AWS-7-F | DARR200 | Diodes Incorporated | SD103AWS-7-F | SOD-323-2 |  |  |  |  |  |  | 1 | https://www.mouser.fr/ProductDetail/Diodes-Incorporated/SD103AWS-7-F?qs=yDXQ%2Fb33kn1tCz%252Bb09bzhg%3D%3D
not use | Connecteurs USB USB Type C, 2.0, Rec, TH , G/F, RA , Top Mnt, T & R | USB4085-GF-A | J200 | GCT | USB4085-GF-A | 0402 |  |  |  |  |  |  | 1 | https://www.mouser.fr/ProductDetail/GCT/USB4085-GF-A?qs=KUoIvG%2F9Ilba1bQOahfWjw%3D%3D
not use | Conn Unshrouded Header HDR 10 POS 2.54mm Solder ST Thru-Hole Carton | TE_1-826629-0 | J201, J202 | TE Connectivity | TE_1-826629-0 | 0402 |  |  |  |  |  |  | 2 | https://www.mouser.fr/ProductDetail/TE-Connectivity/1-826629-0?qs=FazuUmncXom0aPLI6ZgGxg%3D%3D
not use | WURTH ELEKTRONIK - 61300211121 - HEADER, 2.54MM, PIN, THT, VERTICAL, 2WAY | 61300211121 | J203 | Wurth Elektronik | 61300211121 | 0402 |  |  |  |  |  |  | 1 | https://www.mouser.fr/ProductDetail/Wurth-Elektronik/61300211121?qs=t4813l51qx%252B1A5GYDQxPlw%3D%3D
not use | Bobine | 1.8nH | L100 | Murata Electronics | LQG15HH1N8S02D | 0402 |  |  |  | 0.3 nH |  |  | 1 | https://www.mouser.fr/ProductDetail/Murata-Electronics/LQG15HH1N8S02D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
not use | Bobines / filtres en mode commun WE-CNSW 1206 370mA 90Ohm 100MHz AECQ200 | 744232090 | L200 | Wurth Elektronik | 744232090 | 1206 (3216 metric) |  |  |  |  |  |  | 1 | https://www.mouser.fr/ProductDetail/Wurth-Elektronik/744232090?qs=PGXP4M47uW6L5fAiLO6yTw%3D%3D
not use | Bipolar Transistors - BJT NPN TRANSISTOR 1.5A 40V | SS8050-G | Q100, Q101 | Comchip Technology | SS8050-G | SOT-23-3 |  |  |  |  |  |  | 2 | https://www.mouser.fr/ProductDetail/Comchip-Technology/SS8050-G?qs=LLUE9lz1YbcHg%252BWLMAtcrQ%3D%3D
not use | MOSFET P-Channel MOSFET | SI3139K-TP | Q102, Q200 | Micro Commercial Components (MCC) | SI3139K-TP | SOT-723-3 |  |  |  |  |  |  | 2 | https://www.mouser.fr/ProductDetail/Micro-Commercial-Components-MCC/SI3139K-TP?qs=MoCBKJu1Jj02PHzM5h1rLQ%3D%3D
not use | BSS123 N-Channel MOSFET, 170 mA, 100 V PowerTrench, 3-Pin SOT-23 ON Semiconductor | BSS123 | Q103 | onsemi / Fairchild | BSS123 | SOT-23-3 |  |  |  |  |  |  | 1 | https://www.mouser.fr/ProductDetail/onsemi-Fairchild/BSS123?qs=FOlmdCx%252BAA2Kf8SEB3qLYA%3D%3D
not use | Resistor | 4.7K | R100 | TE Connectivity / Holsworthy | CRGCQ0402J4R7 | 0402 |  |  |  | 5% |  |  | 1 | https://www.mouser.fr/ProductDetail/TE-Connectivity-Holsworthy/CRGCQ0402J4R7
not use | Resistor | 10K | R101, R102, R104, R204 | TE Connectivity / Holsworthy | RN73C1E10KBTD | 0402 |  |  |  | 0.1% |  |  | 4 | https://www.mouser.fr/ProductDetail/TE-Connectivity-Holsworthy/RN73C1E10KBTD
not use | Resistor | 510R | R103 | TE Connectivity / Holsworthy | CRG0402F510R | 0402 |  |  |  | 1% |  |  | 1 | https://www.mouser.fr/ProductDetail/TE-Connectivity-Holsworthy/CRG0402F510R
not use | Resistor | 100K | R105, R106, R107, R200, R205 | TE Connectivity / Holsworthy | CPF0402B100KE | 0402 |  |  |  | 0.1% |  |  | 5 | https://www.mouser.fr/ProductDetail/TE-Connectivity-Holsworthy/CPF0402B100KE
not use | Resistor | 5K1 | R201, R203 | TE Connectivity / Holsworthy | CRG0402F5K1 | 0402 |  |  |  | 1% |  |  | 2 | https://www.mouser.fr/ProductDetail/TE-Connectivity-Holsworthy/CRG0402F5K1
not use | Resistor | 470R | R202 | TE Connectivity / Holsworthy | CRG0402F470R | 0402 |  |  |  | 1% |  |  | 1 | https://www.mouser.fr/ProductDetail/TE-Connectivity-Holsworthy/CRG0402F470R
not use | Système RF sur puce - SoC SIP module ESP32 with 4MByte Flash, Dual Core MCU, Wi-Fi & Bluetooth Combo, LGA48-pin, 7*7mm | ESP32-PICO-D4 | U100 | Espressif Systems | ESP32-PICO-D4 | QFN-48 |  |  |  |  |  |  | 1 | https://www.mouser.fr/ProductDetail/Espressif-Systems/ESP32-PICO-D4?qs=MLItCLRbWsw7MJlbN3HfdA%3D%3D
not use | USB Bridge, USB to UART USB 2.0 UART Interface 24-QFN (4x4) | CP2104-F03-GM | U101 | Silicon Labs | CP2104-F03-GM | QFN-24 |  |  |  |  |  |  | 1 | https://www.mouser.fr/ProductDetail/GCT/USB4085-GF-A?qs=KUoIvG%2F9Ilba1bQOahfWjw%3D%3D
not use | SRAM 8Mb, SerialRAM, 2.7V-3.6V, 104MHz, 8 pin SOIC 150 mil, RoHS | IS66WVS1M8BLL-104NLI | U102 | ISSI | IS66WVS1M8BLL-104NLI | SOIC-8 |  |  |  |  |  |  | 1 | https://www.mouser.fr/ProductDetail/ISSI/IS66WVS1M8BLL-104NLI?qs=doiCPypUmgGxZh5L3cgVoQ%3D%3D
not use | Gestion de batterie/pile Charge mgnt contr | MCP73831T-3ACI/OT | U200 | Microchip Technology | MCP73831T-3ACI/OT | SOT-23-5 |  |  |  |  |  |  | 1 | https://www.mouser.fr/ProductDetail/Microchip-Technology/MCP73831T-3ACI-OT?qs=yUQqVecv4quInAWkk8YFWg%3D%3D
not use | Régulateurs de tension LDO LDO 700 MA ULTRA-LOW NOISE 3.3V | NCP167BMX330TBG | U201 | onsemi | NCP167BMX330TBG | XDFN-4 |  |  |  |  |  |  | 1 | https://www.mouser.fr/ProductDetail/onsemi/NCP167BMX330TBG?qs=MLItCLRbWsxdhppZpZlnwg%3D%3D
not use | Black Tactile Tactile Switch, NO 50 mA 0.5mm Surface Mount | 430481025816 | X100 | Wurth Elektronik | 430481025816 |  |  |  |  |  |  |  | 1 | https://www.mouser.fr/ProductDetail/Wurth-Elektronik/430481025816?qs=wr8lucFkNMXXxhyqbLxcbg%3D%3D

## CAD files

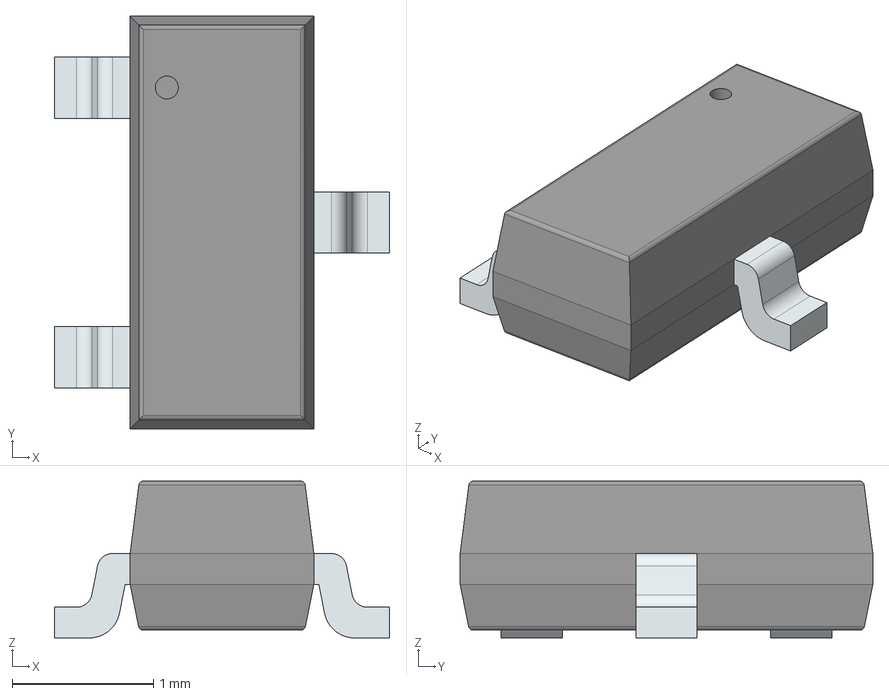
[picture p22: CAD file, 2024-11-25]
3d/2N7002KT1G/2N7002KT1G.stp
2.37 x 2.92 x 1.11 mm
PinsArrayL
FilletPinR

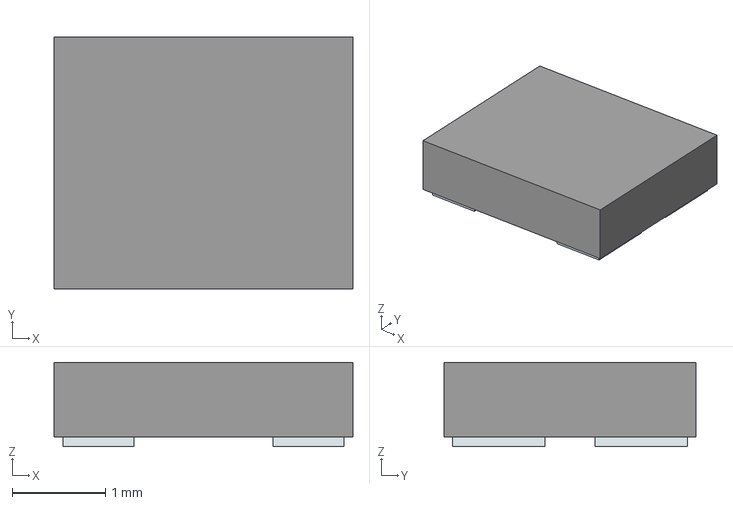
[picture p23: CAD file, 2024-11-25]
3d/598-8610-207F/598-8610-207F.stp
3.20 x 2.70 x 0.9 mm
Pins

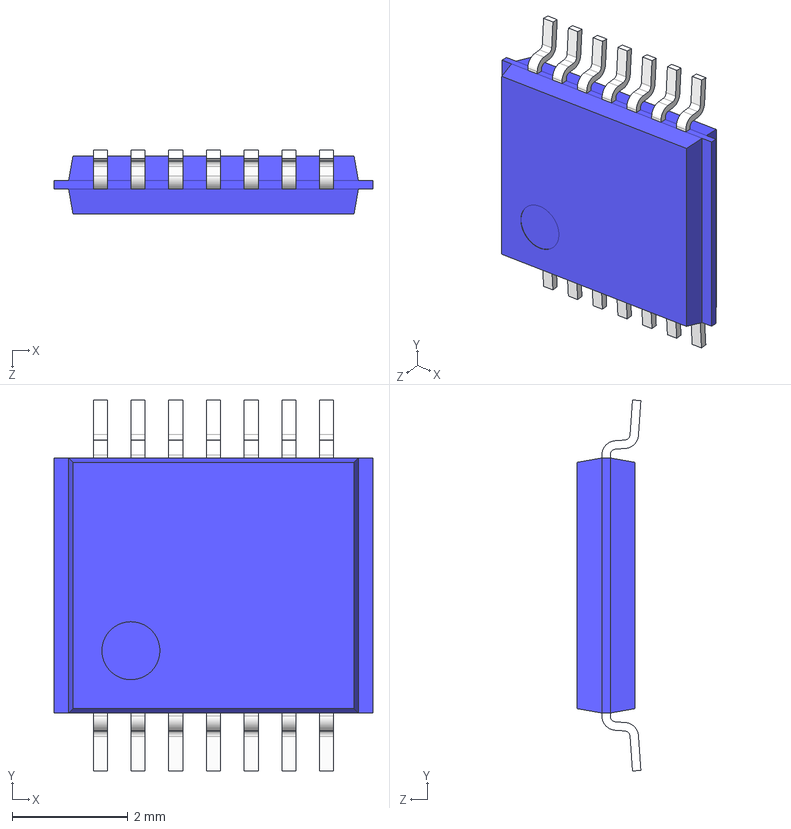
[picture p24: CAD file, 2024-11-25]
3d/74VHC05FT/74VHC05FT.stp
5.50 x 6.40 x 1.10 mm

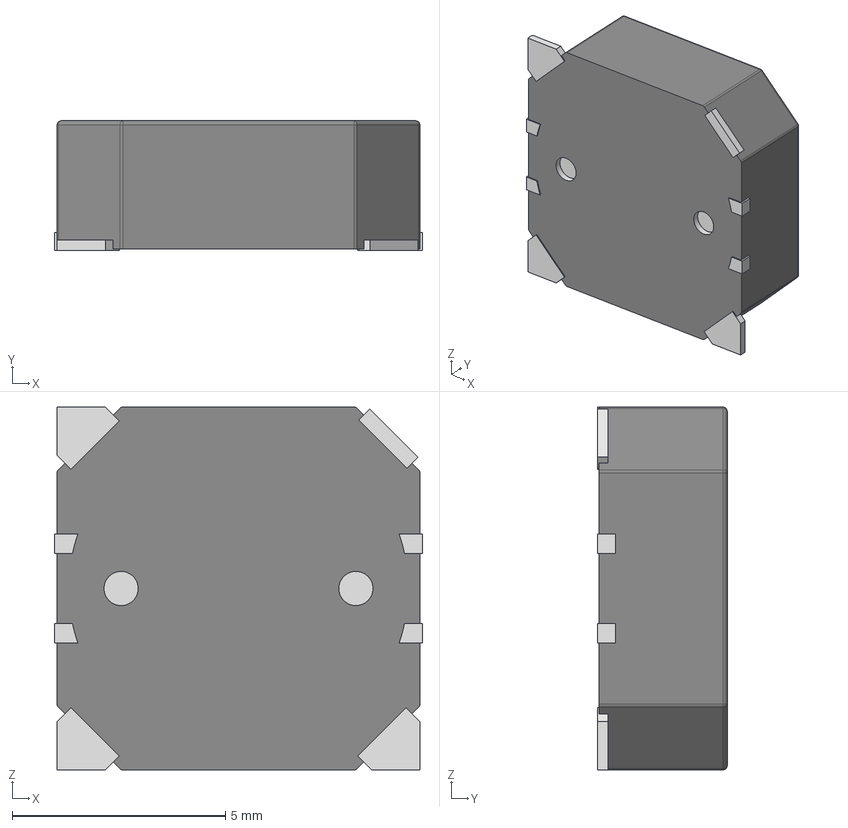
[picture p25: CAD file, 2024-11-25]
3d/CMT-8503-85B-SMT-TR/CMT-8503-85B-SMT-TR.stp
8.62 x 3.04 x 8.50 mm

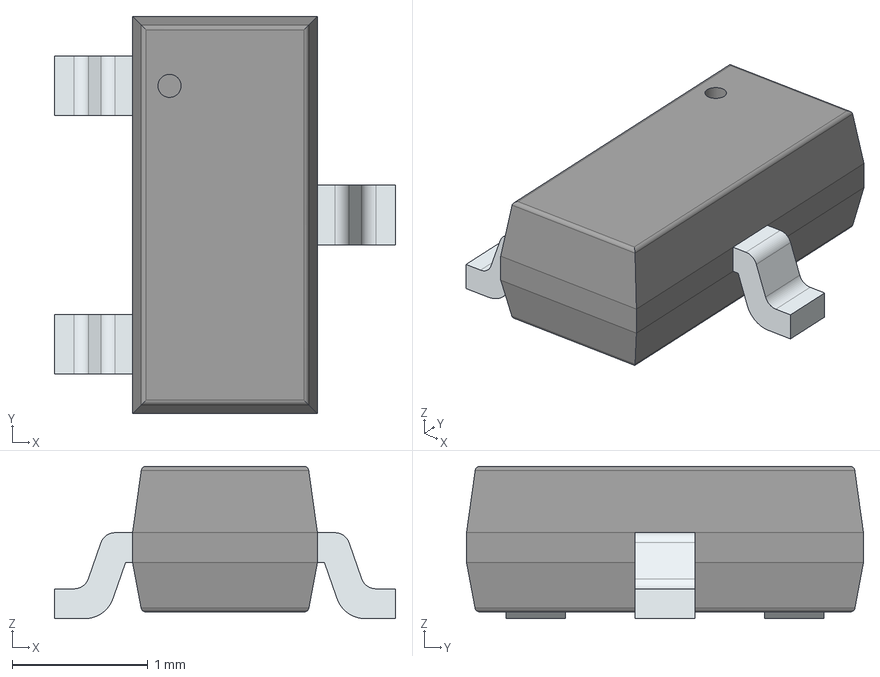
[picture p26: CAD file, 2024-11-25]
3d/FDV304P/FDV304P.stp
2.51 x 2.92 x 1.12 mm
PinsArrayL
FilletPinR

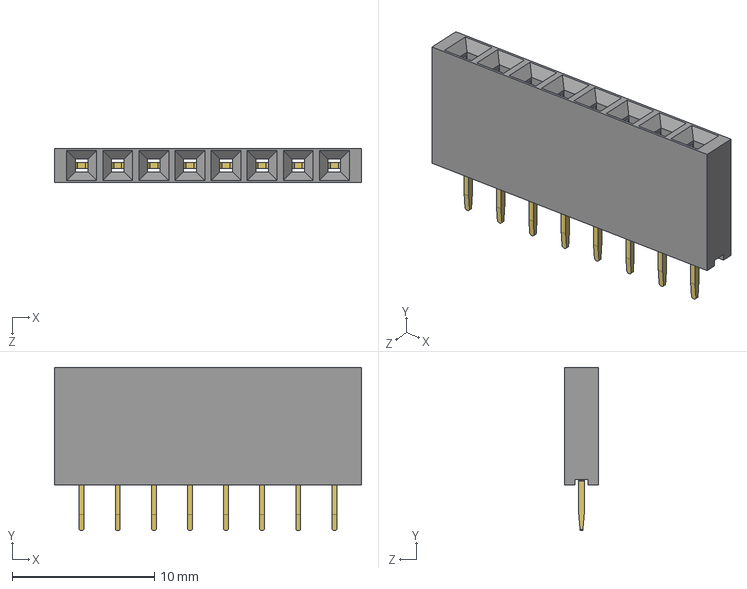
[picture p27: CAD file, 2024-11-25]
3d/female-pitch-connector-2-54-mm-x8/2_54_x_8_pitch_connector_.STEP
21.6 x 11.5 x 2.40 mm
Pitch_x_8
Plastic_x_8

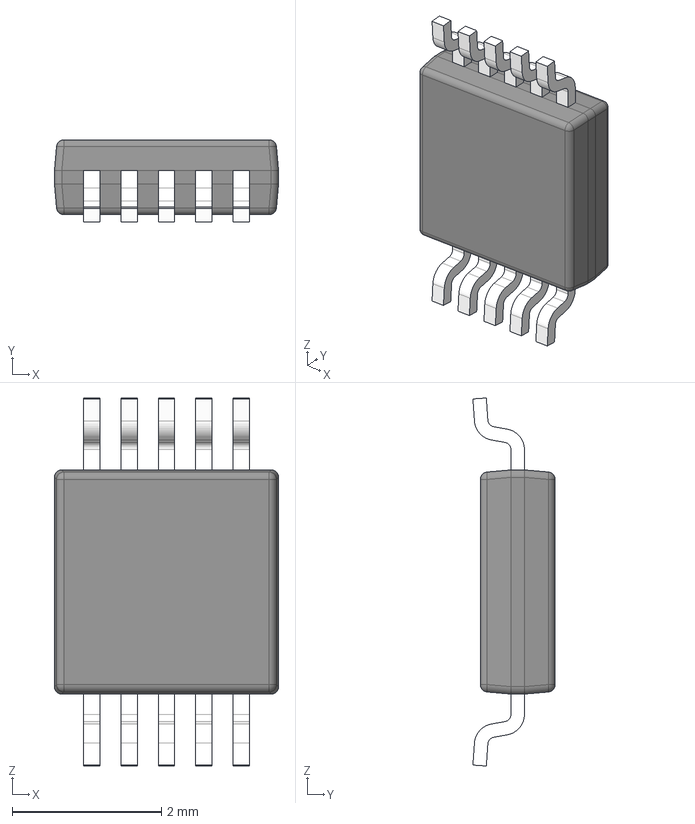
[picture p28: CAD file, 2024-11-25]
3d/INA237AIDGST/INA237AIDGST.stp
3.00 x 1.10 x 4.93 mm
BODY-SO
LEAD-SO x 10
PIN1-ID

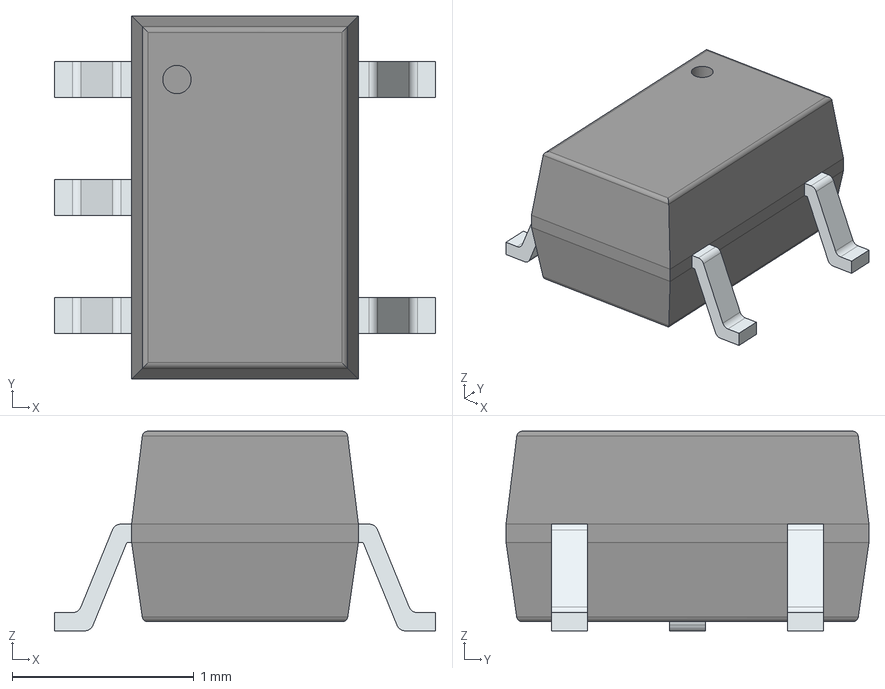
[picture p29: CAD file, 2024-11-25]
3d/MC74VHC1GT08DFT2G/MC74VHC1GT08DFT2G.stp
2.10 x 2.00 x 1.10 mm
PinsArrayL
PinsArrayR

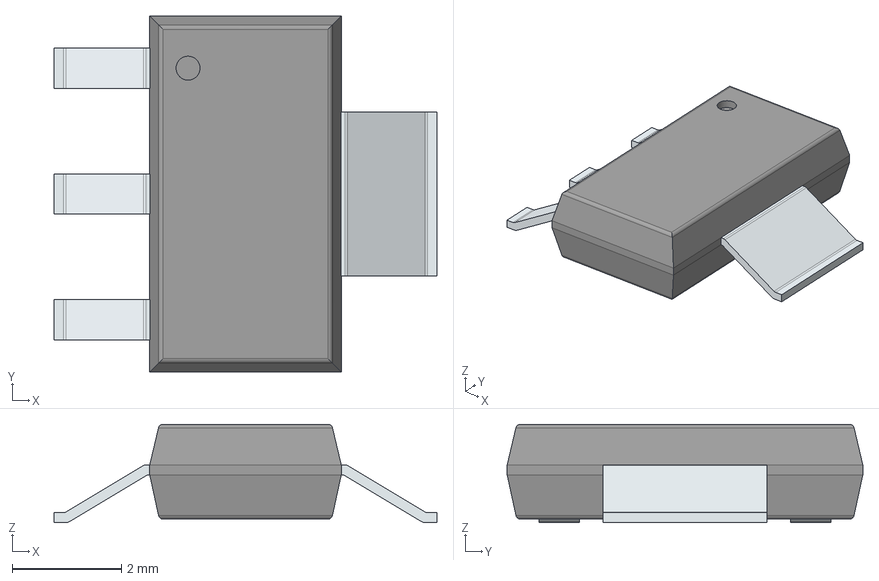
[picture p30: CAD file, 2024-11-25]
3d/NCP1117IST33T3G/NCP1117IST33T3G.stp
7.00 x 6.50 x 1.80 mm
PinsArrayL
FilletPinR

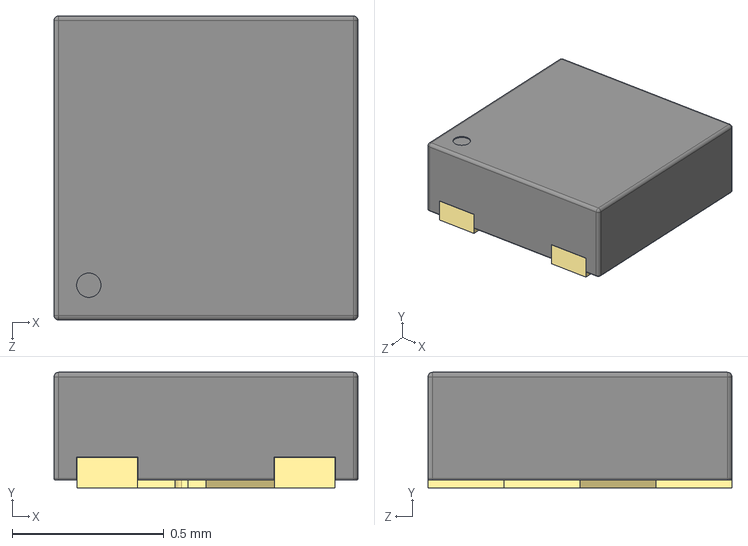
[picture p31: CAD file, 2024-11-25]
3d/NCP167BMX330TBG/NCP167BMX330TBG.stp
1.00 x 0.38 x 1.00 mm

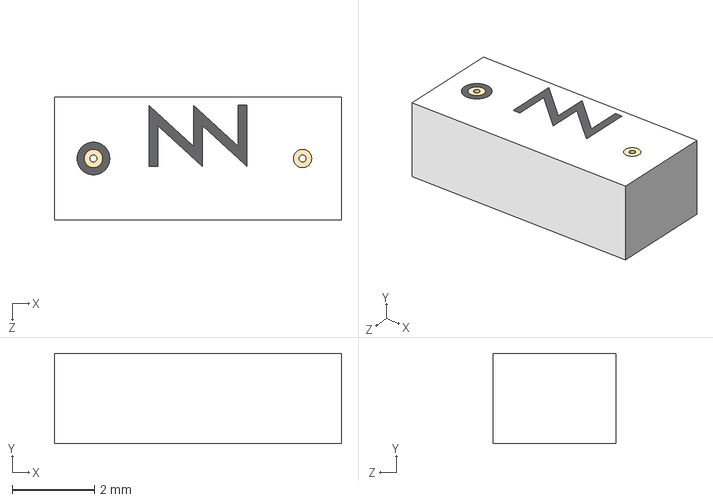
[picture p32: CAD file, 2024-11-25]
3d/NN01-102/NN01-102.step
7.00 x 2.20 x 3.00 mm

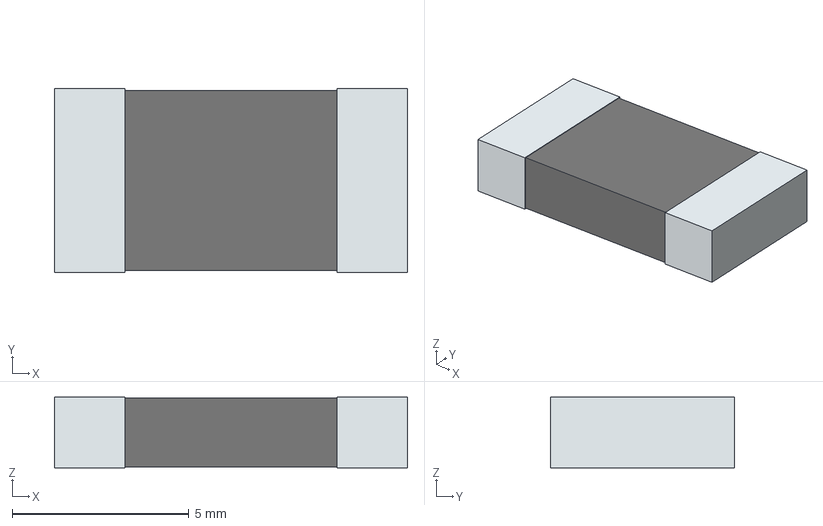
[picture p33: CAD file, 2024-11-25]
3d/PSR400ITQFF0L50/PSR400ITQFF0L50.stp
10.0 x 5.20 x 2.00 mm
term1
term2

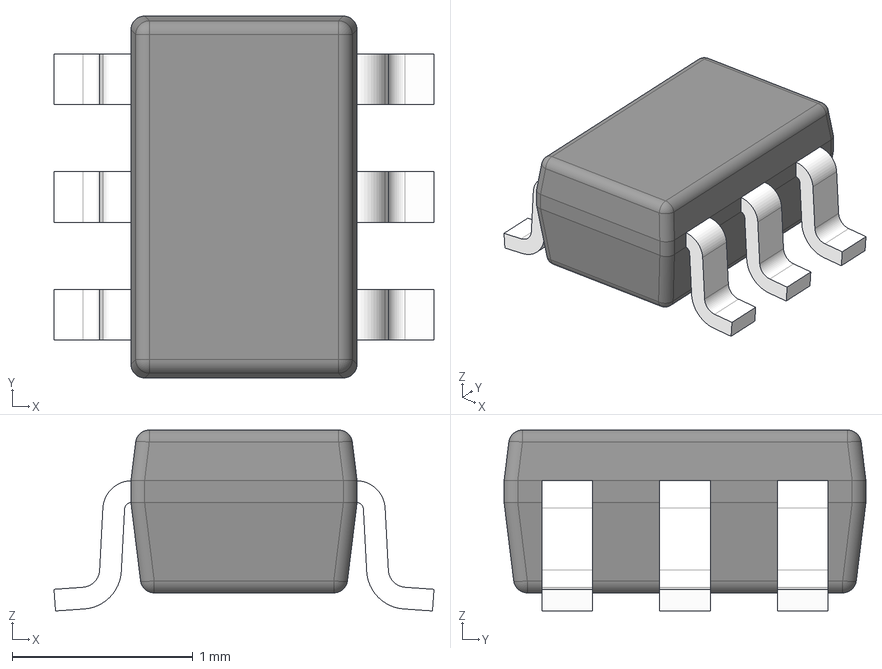
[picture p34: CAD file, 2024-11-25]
3d/TMP126DCKR/TMP126DCKR.stp
2.10 x 2.00 x 1.00 mm
BODY-SOT
LEAD-SOT x 6
PIN1-ID

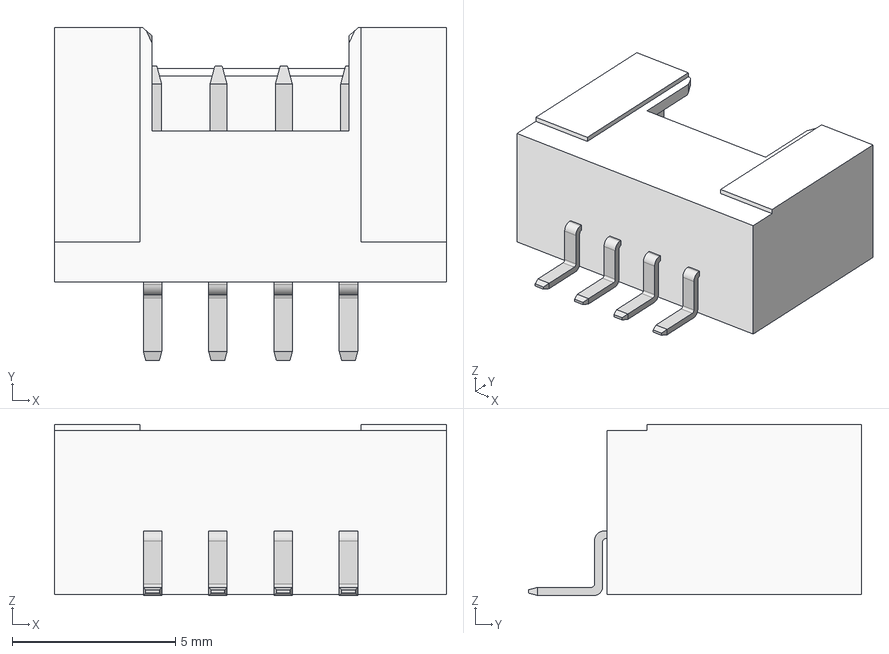
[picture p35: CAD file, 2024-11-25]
3d/114020164/114020164.stp
12.0 x 10.2 x 5.24 mm

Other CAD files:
3d/BSS123LT1G/BSS123LT1G.stp
3d/MC74VHC1GT32DFT1G/MC74VHC1GT32DFT1G.stp
3d/430481025816/430481025816.stp
3d/744232090/744232090.stp
3d/824011/824011.stp
3d/825433-8/825433-8.stp
3d/LMR50410Y3FQDBVRQ1/LMR50410Y3FQDBVRQ1.stp

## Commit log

2024-11-07 Circuit_Logique_Alimentation_1.sim added
    Circuit_Logique_Alimentation_1
2024-11-25 add ihm branch in the same schematic as esp32
    [114020164.stp, 2N7002KT1G.stp, 2_54_x_8_pitch_connector_.STEP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]
2024-11-25 add ihm separated schematic
    [IHM.SchDoc, Sheet1.SchDoc]
2024-11-25 add annotations in ihm and sheet 1
    [ESP32_Projet.PrjPcb, IHM.SchDoc, Sheet1.SchDoc]
2024-11-25 add alim schematic without USB and Logic
    [alim.SchDoc]
2024-11-26 add sensors branch
    [ESP32_Projet.PrjPcb, PCBLibrary.PcbLib, SCHLibrary.SchLib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]
2024-11-26 add connecteurs
    [ESP32_Projet.PrjPcb, connecteurs.SchDoc]
2024-11-26 add Bluetooth branch
    [Bluetooth.SchDoc, ESP32_Projet.PrjPcb]
2024-11-26 add schematic protocole
    [protocoles de comm.SchDoc]
2024-11-26 update IHM buzzer and alim
    [IHM.SchDoc, alim.SchDoc]
2024-11-26 update IHM and alim
    [IHM.SchDoc, alim.SchDoc]
2024-11-26 Update Bluetooth and Sensors rename MCU_Sheet
    [Bluetooth.SchDoc, ESP32_Projet.PrjPcb, MCU_ESP32.SchDoc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]
2024-11-28 update alim USB port
    [ESP32_Projet.PrjPcb, alim.SchDoc]
2024-11-28 Update sensors, add BT, layout schematic, delete Bluetooth
    [Bluetooth.SchDoc, ESP32_Projet.PrjPcb, Sensors.SchDoc]
2024-11-28 finish connecteurs and protocoles and mcu
    [ESP32_Projet.PrjPcb, MCU_ESP32.SchDoc, connecteurs.SchDoc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]
2024-11-28 update IHM LED, Buzzers and Layout
    [IHM.SchDoc]
2024-11-28 update project file
    [ESP32_Projet.PrjPcb]
2024-11-28 update mcu port protocoles
    [MCU_ESP32.SchDoc, protocoles de comm.SchDoc]
2024-11-28 update alim layout
    [alim.SchDoc]
2024-11-28 update mcu, connecteurs, protocole
    [MCU_ESP32.SchDoc, connecteurs.SchDoc, protocoles de comm.SchDoc]
2024-11-28 correction des erreurs avec validate sch
    [ESP32_Projet.PrjPcb, IHM.SchDoc, MCU_ESP32.SchDoc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]
2024-12-09 correction des 'off grid'
    [MCU_ESP32.SchDoc, Sensors.SchDoc, connecteurs.SchDoc]
2024-12-11 Update Schematic clear warnings
    [IHM.SchDoc, MCU_ESP32.SchDoc, PCB1.PcbDoc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]
2024-12-11 Update PCB_connector_protocol comm
    [PCB1.PcbDoc]
2024-12-12 routage sensor and alim and ihm not finished
    [ESP32_Projet.PrjPcb, MCU_ESP32.SchDoc, PCB1.PcbDoc]
2024-12-15 probleme non résolu
    [ESP32_Projet.PrjPcb, PCB1.PcbDoc]
2024-12-16 uptdate routage
    [PCB1.PcbDoc]
2024-12-16 assil make something
    [connecteurs.SchDoc]
2024-12-16 Project done
    [IHM.SchDoc, MCU_ESP32.SchDoc, PCB1.PcbDoc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]
